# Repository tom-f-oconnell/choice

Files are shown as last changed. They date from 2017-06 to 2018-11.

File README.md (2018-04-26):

### Installation
1. [Install ROS Kinetic](http://wiki.ros.org/kinetic/Installation) on a supported operating system.  
   - Tested on [Ubuntu 16.04](https://www.ubuntu.com/download/desktop).
   - You can install Ubuntu alongside Windows with minimal effort.
   - Other ROS versions may work, but tested with Kinetic.
   - You only need `ros-kinetic-ros-base`.
      - You do *NOT* need everything in `ros-kinetic-desktop-full`, and it takes more disk space and install time.

2. Install the catkin packages.
   See ROS [tutorial on making a catkin workspace](http://wiki.ros.org/catkin/Tutorials/create_a_workspace).

   If you have not already, add a line to your `~/.bashrc` that loads the development setup script (that catkin generates), such as:
   ```
   source <your_catkin_workspace>/devel/setup.bash
   ```

   Then this should install all the packages you need:
   ```
   cd <your_catkin_workspace>/src
   git clone https://github.com/tom-f-oconnell/multi_tracker.git
   git clone https://github.com/tom-f-oconnell/usb_cam.git
   git clone https://github.com/tom-f-oconnell/rosserial.git
   git clone https://github.com/tom-f-oconnell/metatools.git
   git clone https://github.com/tom-f-oconnell/stimuli.git
   git clone https://github.com/tom-f-oconnell/choice.git
   cd <your_catkin_workspace>
   catkin_make
   . ~/.bashrc
   ```

   The last line loads `<your_catkin_workspace>/devel/setup.bash` because of the line you added to your `~/.bashrc` in the previous step.

   On all of the computers in the Hong lab, the catkin workspace can be found at `~/catkin`, for whichever user account was used to run the experiments.

   Currently, only installation from source is supported. In the future, I would like to make this installable as a ROS package via apt, but that would likely also require the same of `multi_tracker`, and there are some technical reasons that won't be possible right now with ROS Kinetic.

3. Upload the firmware to an Arduino MEGA
   1. Download and unzip Arduino to a path you will remember, or locate it if already installed.
      - Version ~1.5 - 1.8.3 should definitely work. Nearby versions almost certainly also will. You should get error messages when compiling if things do not work, and if this is the case you may need to use a different version of Arduino.
      - Arduino older than or equal to 1.0 will likely not work.
      - I unzipped Arduino to my home directory, which came out as as `~/arduino-1.8.3`, which I will use as an example.
   2. `cd ~/arduino-1.8.3/libraries` (or wherever your Arduino is installed)
   3. `rm -rf ros_lib` (in case some libraries have already been generated)
   4. `rosrun rosserial_arduino make_libraries.py .`
   5. Symlink to `stimuli` and `multishock` libraries. You only need
      `multishock` if uploading code that relies on the shift-register based
      shock control hardware.

      (still from `~/arduino-1.8.3/libraries`)
      ```
      ln -s ~/catkin/src/stimuli/arduino/libraries/stimuli
      ln -s ~/catkin/src/choice/arduino/libraries/multishock
      ```

   6. If you Arduino IDE was open, close and re-open it.
      - *Make sure that you are opening the same version of Arduino you installed the libraries for.* It is easier to only have one version of Arduino installed at any given time to avoid these conflicts.

   7. Add your user to the `dialout` group (if on Ubuntu), to be able to upload code.
      - `sudo adduser <username> dialout`
      - Log out and back in for the change to take effect

   8. Connect your Arduino MEGA to the computer.
      - Arduino's with less memory will currently **NOT** work, as there is considerable overhead in the generated ROS libraries.

   9. Upload code 
       
      For the basic stimulus delivery, open `File->Examples->stimuli->stimuli` 
      In the Arduino IDE, under the `Tools` menu:
      - Select appropriate port
         - Usually `/dev/ttyUSBX`, where `X` could vary. `/dev/ttyACMX` may also work. It is never the one like `/dev/ttyS0`.
         - May have the correct board model in parentheses after the port name
      - Select appropriate board (probably `Arduino/Genuino Mega or Mega 2560`)
      - Press the Upload button in the top left of the IDE
         - It looks like a circle with a righward arrow in it.
      - If the TX / RX lights flash on the Arduino, and the Upload seems to finish, you should be good to go.

4. *(Optional)* Set an alias for running `roslaunch` with a different `ROS_HOME` environment variable.

To load the configuration files from (and to save the output directory to) the current directory, I prefix the `roslaunch choice choice.launch` command with `ROS_HOME=``pwd```. To make all `roslaunch` invokations behave this way, which works for my purposes, you can make an alias for `roslaunch`.

If you don't already have a ~/.bash_aliases file, you can create one by opening it in a text editor, otherwise just open the file you already have. Add a line that says:
```
alias roslaunch='ROS_HOME=`pwd` roslaunch'
```

Save and close the file, and reload your terminal environment by typing `. ~/.bashrc`, or opening a new terminal. Now you can just type `roslaunch choice choice.launch`, and it will load configuration input from the current directory and save output there as well.

### Manufacture

TODO link to a readme in the design folder / wiki?

### Running an experiment

#### Requirements
The current directory has at least the following configuration files:
##### For tracking
- tracker_parameters.yaml
- roi_finder.yaml
- delta_video_parameters.yaml

- If running the tracking in real-time, also:
   - liveviewer_parameters.yaml
   - data_association_parameters.yaml
   - kalman_parameters.py

##### For stimulus
- stimulus_parameters.yaml

Depending on the camera you are using, you may also want to include parameters for your camera node, which you will have to load separately. There are some examples in the `multi_tracker` repository.

To copy templates for each of these configuration files to your current directory:
```
rosrun choice copy_configs.py
```

##### To set the length of the experiment
In the `stimulus_parameters.yaml` file, set the parameters starting at `olf/training_blocks` and ending at `olf/beyond_posttest_s` to appropriate values.

In `tracker_parameters.yaml`, set `multi_tracker/record_length_hours` to -1, so
that the length of the recording is determined by the stimulus presentation.

#### To run a full experiment with real-time tracking on the same computer.
Requires a computer with adequate memory and processor.
```
roslaunch choice choice.launch
```

##### Errors (red text)
The only error message that is normal during startup is one along the lines of `Parameter stimulus_arduino/debug does not exist`. Another other red text means something is likely not working, and you should not ignore it.

##### Warnings (yellow text)
`Failed to get param: timeout expired` is normal, as long as the program ultimately stops 
emitting these warnings. You should be aware of the reasons other warnings occur. 
Contact Tom with any questions.

#### To run an experiment saving a background subtracted video in a ROS bag file, for offline tracking.
Less hardware demands.
```
roslaunch choice choice.launch video_only:=True
```

##### Possible problems

If you run `rosparam list` before starting an experiment, you should see
`ERROR: Unable to communicate with master!`, otherwise, the existing parameters
can misconfigure any experiments you try to run.

First, check it isn't a valid experiment being run on another account, if you're
sharing the computer. If not, you should be able to stop the existing `roscore`
process with:
```
sudo pkill rosmaster
```

After this command, you another `rosparam list` should give you
```
ERROR: Unable to communicate with master!
```

### Stimulus Validation

To run the stimulus presentation that would happen during an experiment, but without any 
recording or tracking. For measurement / verification / PID purposes.
```
roslaunch choice choice.launch stimuli_only:=True
```

To run simpler pulse trains of a given duration, without changing the code on the Arduino. 
This launch file will also look for a `stimulus_parameters.yaml` file in the same path, but
with slightly different parameters.
```
roslaunch stimuli pid.launch seconds:=30
```

See [this repo](https://github.com/tom-f-oconnell/stimuli#validation) for more information 
on the parameters and launch file arguments for `pid.launch`.

To test the valves (I run this before and after each experiment, to make sure no connections came loose. With more robust electronics this might be less of a concern.)
- The number of the pin to be switched will be printed in the terminal you run the launch file from.
- I attach higher pressure air to all valves and check manually for air flow at each pin that should be switched.
```
roslaunch stimuli test_valves.launch
```

Press `<Ctrl>-C` to stop the `test_valves.launch` file.

### Offline tracking

#### Requirements
- The environment variable `DATA_DIR` is set to a path you will keep your data directories beneath.
   - I organize my experiment directories as grandchildren of `DATA_DIR`, grouping them as I see fit with directories (of arbitrary names) just beneath `DATA_DIR`.
   - To test that this is set, you can run `echo $DATA_DIR`, and the path should be printed.
   - To set this:

     Add a line to your `~/.bashrc` file like:

     ```
     export DATA_DIR="<full_path_to_data_directory>"
     ```

     For instance, mine has this line:
     ```
     export DATA_DIR="$HOME/data"
     ```

     Then, either start a new terminal, or run `. ~/.bashrc`, so that the change in the environment variable takes effect.

- `$DATA_DIR/retracked` exists and has all of the configuration files required for tracking (see requirements for running an experiment above)
- All of the installation instructions for at least ROS and the `multi_tracker` package are done.

On any computer satisfying these requirements, run:
```
rosrun multi_tracker retrack_ros <experiment_directory> <decimal_valued_rate>
```

The `<decimal_valued_rate>` can be set as high as does not produce a stream of warning messages that does not improve until the tracking finishes.  If the computer appears to be straining, you may also want to decrease the rate.  If you want to also employ more limited computers for tracking lots of data, you are also able to decrease the rate beneath 1.0 if necessary.

The default rate is currently 0.8, if no rate is provided. Our analysis workstations can track up to a rate of 4.0 - 5.0, with little issue.

The `<experiment_directory>` can be any of:
- ~~a path to a valid directory~~
- ~~a file within a valid directory~~
- the name of a subdirectory beneath `$DATA_DIR`, if the `DATA_DIR` environment variable is set
   - the way this script currently finds the output path, it requires `DATA_DIR`, so you should use this option for now.

A valid directory has:
- at a minimum:
   - a name in the `YYYYMMDD_HHMMSS` format
   - a bag file
   - any background PNGs that were in the same directory
   - a file with the ROIs called `compressor_rois_<experiment_id>.yaml`
- ideally, all files generated during acquisition, including also:
   - a `*_parameters.yaml` file
   - a `*_stimuli.p` file

#### Example
```
rosrun multi_tracker retrack_ros 20170930_164433 2.0
```

In this example, `DATA_DIR` was set with a line in my `~/.bashrc` file as:
```
export DATA_DIR="$HOME/data"
```
and `/home/tom/data/20170920/20170930_164433` was a valid directory. Note that `20170930_164433` was not a direct child directory of `DATA_DIR`. The code may currently expect the `<experiment_directory>` to be a granchild of `DATA_DIR`, if this option is selected.

#### Output
After running the tracking, the valid directory you provided as input will also have:
- An HDF5 file with a the variables the tracker is estimating, over time
   - The `position_x` and `position_y`

#### Copying data from acquisition to tracking / analysis computer

You are of course free to copy the files via other means. This may just end up being convenient.

#### Requirements
- Both computers have internet access
- The computer you are trying to connect TO has an SSH server installed and running
   - Look up how to install OpenSSH server for the operating system you are using if you need to do this.

```
rsync -auvPzr <folder_with_data> user@<server_ip_address>:~/<place_to_put_it>
```

The rsync command with those flags seems not to work if you include a trailing slash after the `<folder_with_data>` name.

#### Example
```
rsync -auvPzr ~/data/. tom@gerty:~/data
```
This example will recursively copy all subdirectories of data, and I keep all my experiment directories nested within here.

#### Known bugs + workarounds
If you notice your computer working harder than it should when the acquisition / tracking should otherwise have terminated, you can run `top` or some other process manager, and check for a handful of processes, owned by the same user that ran the launch file, with names including:
- `play`
- `record`
- `python`
- `<something>launch` ?

And assuming you are OK killing all ROS processes currently running on your computer, you can try running:
- `killall roscore`
- `killall roslaunch`
- `killall play`

Under some circumstances, you may also want to kill all python processes owned by the user that started the ROS processes, with `killall python`.

### Analysis
#### Requirements
(To be added )
- `DATA_DIR` is set as in offline tracking instructions.
- `choice` and `multi_tracker` are installed as above (though you don't technically need all of ROS)
- The experiments you want to analyze together have their data folders grouped within an immediate subdirectory of `$DATA_DIR/retracked`.
   - If your tracking output comes from real-time tracking, it does not need to be treated differently, apart from copying it to a subdirectory beneath `$DATA_DIR/retracked`.
- The `ruamel.yaml` package, which you should be able to get via:
   ```
   cd <choice>
   pip install -r requirements.txt
   ```
   Again, if you need root access to install via `pip`, use `sudo` as above.

#### Running
```
rosrun choice choice_analysis <subdirectory>
```

If, across all analysis runs *that have used this folder as input*, you have not already labelled all experiments as either good or needing rejection for some reason, a GUI should open asking you to label the traces appropriately. See the terminal output for which keys correspond to which labels.

The output of this labelling should be saved as `$DATA_DIR/retracked/<subdirectory>/analysis_rejects.yaml`. It is human readable, and you can edit it by hand in a text editor if you want to change something. If you want to start the labelling over, feel free to delete or move / rename `analysis_rejects.yaml`.

Currently, if you want labels to apply across groupings of your data, (across analysis runs with different subdirectories as input) you will need to manually merge the `analysis_rejects.yaml` text files.

#### Output

Within the `$DATA_DIR/retracked/<subdirectory>`, you should find a number of files in a graphics format (svg by default). For each odor, each reject category, and each preference metric (fraction of time spent and "decision bias"), you will find:
- `<metric>.svg`
   - For pooled data of all non-rejects, across all odors.
- `<odor>_<metric>.svg` (or .other_graphic_format, like .png)
   - For pooled data of all non-rejects, within an odor.
- `<reject_category>_<metric>.svg`
   - For data of all rejects of a certain label / category, pooled across odors

There will also be text output, in the terminal in which you ran the analysis, describing the metrics within and across odors, and the fraction of flies in each reject category.

### Updating code

If you have made any changes to your local copies of these repositories that you would like to keep, look up `git stash` and proceed with caution, otherwise:

```
roscd multi_tracker
git pull
roscd choice
git pull
```

Then, repeat the instructions for installing catkin packages above, which should look like:
```
cd <catkin_workspace>
catkin_make
. ~/.bashrc
```

This, again, requires that you have a line in your `~/.bashrc` that "sources" (loads) the file `<catkin_ws>/devel/setup.bash`, or else the line `. ~/.bashrc` will not necessarily apply all updates that have been made to the code.

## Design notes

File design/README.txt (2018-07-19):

If any .svg or .fcstd files are newer than files of the same name with a
different extension (should be .eps and .stl, respectively), then you may want
to delete those .eps and .stl files and re-generate them from the newer source
files before cutting / printing the parts.

SVGs are Inkscape SVGs. Generally I would export these as EPS and then load them
on the computer connected to the laser cutter in Coreldraw.  In Coreldraw, I
would convert all lines to "Hairline" , as this was required for any lines you'd
like to cut (<0.0001" should be treated the same, but it is harder to work with
while designing).

.fcstd files should be openable with FreeCAD. The software is getting a lot
better, so it is worth getting the most recent version from the PPA (you can
look up how to do this). I generally used version 0.17. To export STLs you have
to open the FCSTD file, select an object (on the left, the highest level node
that isn't the name of the document), and then go to File->Export and change the
output file type to STL.  I prepared gcode (instruction for the 3D printer) in
Cura, on Windows, because this is what our librarian showed me how to use.

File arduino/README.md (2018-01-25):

## multishock Arduino library

Wiring/Arduino library to control shock delivery and measurement board. 
Can deliver up to 150v to 16 channels, and measure current through each of them.

### Installation

Copy the `libraries/multishock` directory to one of the library folders for 
your current Arduino installation. This may be `~/Documents/Arduino/libraries/`,
but search online for other situations. This is generally how Arduino 
libraries are installed.

To keep the code update to date more easily, you may want to make a symbolic
link to this directory, rather than copying it. To do this:
```
ln -s /full/path/to/libraries/multishock/ /path/to/arduino/libraries/
```

### Usage

See example sketches. After installing, open / re-open your IDE, and open one 
of the examples under `File->Examples->multishock`

### Testing assembly of the board

See sketches under `examples->tests` folder. Each should explain, at the top of
the file, how to determine whether the test was successful.

TODO

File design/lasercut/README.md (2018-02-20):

- `olfactory_shock_conditioning_chambers.dxf`
   - Master design file for lasercut layers of two choice behavior chambers.
   - Layers in the same plane have the same prefix number (before the period).
   - Lower prefix numbers are layers higher in the assembly.
   - TODO include materials and sources for all layers

- `floor_pcb_edges.dxf` and `ceiling_pcb_edges.dxf`
   - Generated from one version of `olfactory_shock_conditioning_chambers.dxf`
   - Imported into Kicad to the `Edge.Cuts` layer to form the outline and 
     interior routed / drilled features of the floor and ceiling circuit boards.

- `food_vial_holder_no_slider.svg`
   - A prototype food vial holder, to serve as a source of flies for an automatic
     loader.
   - TODO list related parts in 3D printed folder.
   - This master was created in Inkspace. May not load correctly in other programs,
     as it is a special Inkscape SVG format.

- `shaft_output_doubler.dxf`
   - Mounting plates to mate two of the following 70mm gears .
   - Meant to keep the heads of two fly sorters aligned, so when one is at a 
     valid outlet, so is the other.
   - TODO mention related 3D models
- `generated_70mm_gear.svg`
   - TODO how was this generated again? online utility? inkscape script?
   - TODO has this since been copied to `shaft_output_doubler.dxf`? delete?

- `vacuum_trap_for_engraving_0.3.dxf`
   - Prototype of a modular vacuum trap that would be used in isolation.
   - Based quite directly on designs from Ben de Bivort's lab.
   - TODO include laser cutter instructions / power file
- `modular_vacuum_trap.dxf`
   - Unclear whether this was the master or the above was. Neither is rendering 
     properly for me now.

- `smaller_boardcam_mount.dxf`
   - Acrylic adaptor to attach top-down camera to 1" aluminum rail
   - TODO include link to camera / model of one

Other files ending in `.svg` or `.eps` are (potentially outdated) exports 
generated from the `.dxf` of the same name. These are for laser cutting, or use
in other programs. They were generated in Librecad, the same program used to 
draw the master DXFs. These intermediates should load OK in at least Coreldraw.

To get a DXF suitable for import into KiCAD, for use as the outline of the
board:
- Make a copy of the DXF with the edges you want
- In the copy (at least relevant to LibreCAD):
  - delete all layers / features other than the edges
  - select any blocks in your design and `Tools->Modify->Explode` them
  - delete all blocks
- (temporarily) change page settings in KiCAD PCB Layout Editor view of either
  the ceiling or the floor board, whichever you want to import new edges to.
  - `File->Page Settings->Orientation->Landscape`
- `File->Import->DXF`
- Change page settings back to portrait, so boards fit on page for printing.

TODO put this in a README in PCB directories somewhere
To generate negative of copper layer for etchant mask:
- (in KiCAD) `File->Plot`
- Select `SVG` from dropdown
- Check `Mirrored plot` and `Negative plot`
- Change any other settings you want, including perhaps what to do with edges.
- Plot
- Print the SVG output in some program that maintains scale (Inkscape works)

The existing negative is in `design/pcb/gerber/ceiling/<...>.svg`.

#### TODO
- maybe delete all of either the SVGs or the EPS
- maybe generate all of one or both for all files
- maybe store generated files separate from the masters (whether Inkscape SVG or DXF)

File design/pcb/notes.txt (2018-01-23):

power usage (measured):
-v0.1 (manually fixed pinswaps on both power supply ICs)
-all digital chips in, no analog
-all other caps and resistors attached
-2 channels worth of FET / measurement resistors + diodes fully attached
-150R gate resistor on all other channels
-LEDs + 100R with + side on gate and - side on S, in each mosfet socket
-Uno 5V -> 10A fused connection on radioshack true rms meter, negative meter -> shield 5v Uno gnd <-> shield gnd
-Uno powered with 12v, 1A wall-wart. no USB cable connected.
-optoisolator inputs floating

~0.54 A on radioshack meter (on range w/ 1 digit to left of decimal point. in Amps.)
voltage at Vin +/- on DCP020507P (measured with a second meter): ~4.4-(4.6?)v

same, but w/ Mega R3 from Elegoo
v=(~4.4-4.3)->4.2->4.17->still dropping by hundreths of volts after test discontinued 
after a few seconds
I=0.5->0.32

(these two tests actually had the LED + resistors going from gate to drain,
 and so doing nothing, because there was no h.v. power supply attached.
 this was because pinswap of D and S by mistake in v0.1)

TODO why such poor regulation? 12v leaves plenty of headroom, shouldn't it?

TODO do some tests w/ better 5v bench supply, see what current draw would be

-> getting close to needing a separate supply, maybe doing away with the dcp020507
   and just having the lt1118 downstream of a wall wart or something (would need
   this power supply to provide isolation though...)

now with Uno and LED + resistors actually connected from gate to source
V=4.7->4.6ish
I=.625->.6
over maybe 10 seconds

in each of these tests, the Arduino's regulators have gotten fairly hot.
-maybe use diff input voltage?

optoisolator test (on PCB):
-using Uno w/ same wall-wart as above
-test code w/ TEST_ISOLATORS, 3000ms period, all isolator pins on/off
-all digital ICs other than optoisolators (also) disconnected

voltage on output pins of isolators (~0.23, 5) (low, high)
only arduino regulator seems to be getting hot, but not as much as it has
(felt through Arduino PCB)

(limited) test of overvoltage protection
-testing one channel on one of the v0.1 pcbs.
-one channel D->S shunted, no MOSFETs in
-two channels on this PCB fully constructed (diodes, etc) (0 and 15)
    -only these two channels had D,S swap fixed
-other channels just have gate resistor
-all other circuitry assembled (two amplifiers not in sockets though)

3mA @ 120v. for some reason, zener on this channel never seemed to exceed ~2.2V
(test w/ isolated 39K resistor in series w/ same zener produced either 0.8V one
way, or expected 4.8-5.1V the other way)

-using sper scientific 800005 w/ what seems like a K type probe
    -only really able to get a small fraction of the probe's surface on the
     tested part, rest is just exposed to air
    -after ~1-3min @ 120v (was probably still ~3.1mA whole time)
     39K 1W resistor: ~46C (might have seen 48C once)
     zener diode (maybe larger b/c proximity to 39K?: 36(-38?)C
     measurement resistor also in low to mid 30s (presumably entirely b/c
     proximity to 39K)

    -probe is at least also reading ~24.3 @ RT (not sure about calibration
     though). no real reason to think it is off, but haven't tested.

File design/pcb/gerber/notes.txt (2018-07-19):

exported following instructions here:
https://citizengadget.com/post/139813545072/kicad-to-advanced-circuits-for-pcbs-and-assembly

copying important section here:
To generate the gerbers in pcbnew, click plot icon or File->Plot. This Wayne and
Layne post on Gerber generation was super helpful here.

    Layers, probably F.Cu (Top Copper), B.Cu(Bottom Copper) F.Paste(Top Solder
    Paste) F.Silk (Top Silkscreen), B.Silk (Bottom Silkscreen), B.Mask (Bottom
    soldermask), F.Mask (Top soldermask)

    Options, You might have other stuff checked, but the important one is to
    make sure Exclude PCB edge layer from other layers is unchecked as Advanced
    doesn’t take a separate edge cuts layer. Another nicety is check use
    auxiliary axis as origin so when you view in gerbview the file is in the
    center of the screen.

    Gerber Options, click Protel filename Options.

    Finally, Click Plot.

Now to generate the drill file, click Generate Drill File.

    Drill Units, use inches
    Zeros format suppress leading zeros
    Drill Map doesn’t matter
    Files options uncheck mirror y, use minimal header, and if you have non
    plated holes, Advanced takes a separate file for plated and non plated so
    make sure merge pth and npth holes into one file is unchecked.

    Drill Origin Auxiliary axis presuming you used “auxiliary axis as origin” in
    the plot screen. 

    Finally, click Drill File then Close and Close and you Gerbers are in your
    project directory under GerberOutput

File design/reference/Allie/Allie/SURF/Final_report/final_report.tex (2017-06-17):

%%%%%%%%%%%%%%%%%%%%%%%%%%%%%%%%%%%%%%%%%
% University/School Laboratory Report
% LaTeX Template
% Version 3.1 (25/3/14)
%
% This template has been downloaded from:
% http://www.LaTeXTemplates.com
%
% Original author:
% Linux and Unix Users Group at Virginia Tech Wiki 
% (https://vtluug.org/wiki/Example_LaTeX_chem_lab_report)
%
% License:
% CC BY-NC-SA 3.0 (http://creativecommons.org/licenses/by-nc-sa/3.0/)
%
%%%%%%%%%%%%%%%%%%%%%%%%%%%%%%%%%%%%%%%%%

%----------------------------------------------------------------------------------------
%	PACKAGES AND DOCUMENT CONFIGURATIONS
%----------------------------------------------------------------------------------------

\documentclass{article}

\usepackage[version=3]{mhchem} % Package for chemical equation typesetting
\usepackage{siunitx} % Provides the \SI{}{} and \si{} command for typesetting SI units
\usepackage{graphicx} % Required for the inclusion of images
\usepackage{natbib} % Required to change bibliography style to APA
\usepackage{amsmath} % Required for some math elements 

\setlength\parindent{0pt} % Removes all indentation from paragraphs

%\renewcommand{\labelenumi}{\alph{enumi}.} % Make numbering in the enumerate environment by letter rather than number (e.g. section 6)

%\usepackage{times} % Uncomment to use the Times New Roman font

%----------------------------------------------------------------------------------------
%	DOCUMENT INFORMATION
%----------------------------------------------------------------------------------------

\title{Quantitative measurements of olfactory perceptual thresholds in \textit{Drosophila}} % Title

\author{Allie Hexley} % Author name

\date{\today} % Date for the report

\begin{document}

\maketitle % Insert the title, author and date

\begin{center}
\begin{tabular}{l r}
SURF Summer 2016 \\ 
Mentor: Elizabeth Hong 
\end{tabular}
\end{center}

% If you wish to include an abstract, uncomment the lines below
\begin{abstract}
Previous work has identified the molecular, genetic, and circuit substrates for odor-driven behaviors in \textit{Drosophila melanogaster}, but has yet to quantify the performance limits of such odor-driven behaviors. The goal of this project was to make quantitative measurements of the threshold for odor detections and discrimination in \textit{Drosophila} to help better the understanding of the neural codes underlying behavior. In order to make these measurements a purpose built behavioral chamber was built where the \textit{Drosophila} were trained via classical conditioning (via electric shock). The \textit{Drosophila} were presented with two odors and innate preferences noted, and then trained against one of the odors. Following conditioning the \textit{Drosophila} were presented with the aversive odor and neutral odor and post-conditioning preferences were recorded. When training against both 5\% MCH compared to OCT and 3\% MCH compared to OCT, \textit{Drosophila} were able to learn an aversion towards the MCH, but when training against 5\% MCH compared to 3\% MCH or vice versa, the \textit{Drosophila} were unable to learn any aversion. This could be because the \textit{Drosophila} are unable to discriminate between 5\% MCH and 3\% MCH or because the \textit{Drosophila} are generalizing the learned aversion. Future studies must be done with a larger number of concentrations across a greater interval to see how learned aversion varies along the concentration curve, and neuron spike rate should be recorded along the concentration curve also, to show how the change in behavior and change in neural activity relate to each other in order to better quantify perceptual thresholds.
\end{abstract}

%----------------------------------------------------------------------------------------
%	Introduction
%----------------------------------------------------------------------------------------

\section{Introduction}

Previous work has revealed the molecular, genetic, and circuit substrates for odor-driven behaviors in \textit{Drosophila melanogaster} (Wilson, 2013). However there are few measurements of the perfomance limits of such odor-driven behaviors in flies, and these measurements are a necessary step towards understanding the neural codes underlying these behaviors. Whilst the ability of \textit{Drosophila} to discriminate between two different odors, and to have an innate bias towards specific odors has been demonstrated (Parnas \textit{et al.}, 2013), the thresholds for odor detection and discrimination have not yet been identified. My SURF project focused on building custom-built apparatus to probe these thresholds and running experiments to collect preliminary data to begin to make quantitative measurements of the performance limits of odor-driven behaviors. Ultimately the goal of the project is to produce curves showing how \textit{Drosophila} behavior varies with concentration of odor presented and how neuron spike rates change with concentration of odor presented, and to compare the two in order to examine how change in behavior relates to change in neural activity at different concentration changes.\\

\textit{Drosophila melanogaster} were used as the subject of the experiments I ran because they have a numerically compact brain, and a sophisticated genetic toolbox for manipulating circuit functions. Most olfactory neurons are also steretoyped in \textit{Drosophila}, meaning one can find neurons with the same connectivity and physiology in every individual brain. \textit{Drosophila} also have genetic labels for specific neurons and these labels can be used to target specific neurons for electrophysiological measurements. In \textit{Drosophila} odor is detected by the primary olfactory center, the antennal lobe (Tanaka \textit{et al.}, 2012), which has a glomerular structure. Each glomerulus receives input from a certain type of olfactory receptor neuron, creating a map of the odor quality. Output projection neurons innervate the antennal lobe to take information to higher brain regions. This organization of the antennal lobe allows for parallel procession of olfactory input by many parallel coding channels, each of which can be genetically identified.\textit{Drosophila} can be easily trained via Pavlovian conditioning to acquire aversion to a particular odor. It is important that we train the flies used in our studies to ensure that we are driving them to their performance limits in terms of discriminating odor, to ensure that we can quantify the minimum odor concentration difference that the flies are able to distinguish.\\

Pavlovian olfactory conditioning has been used in previous studies (Claride-Chang \textit{et al.}, 2009) to train flies against 4-methycyclohexanol (MCH) and 3-octanol. Claridge-Chang et \textit{al.} used 5\% MCH and 12\% OCT in aversive training against MCH, and found that in mock conditioning (where presentation of MCH was not paired with an electric shock during training), innate preferences were maintained, and in conditioning trials (where presentation of MCH was paired with an electric shock), flies learned aversion against MCH (Figure 1). Claridge-Chang et \textit{al.} also used a behavior chamber design that allowed for individual tracking of fly movements and demonstrated that individual fly preferences changed to become more aversive to MCH during conditioning trials and that individual preferences were not changed during mock conditioning (Figure 2). My SURF project aimed to create a behavior chamber similar to the one used by Claridge-Chang et \textit{al.} to probe perceptual thresholds, and a good test of the effectiveness of this chamber would be to reproduce the Claridge-Chang et \textit{al.} results. \\

%Claridge-Chang group data 1
\begin{figure}[h]
\begin{center}
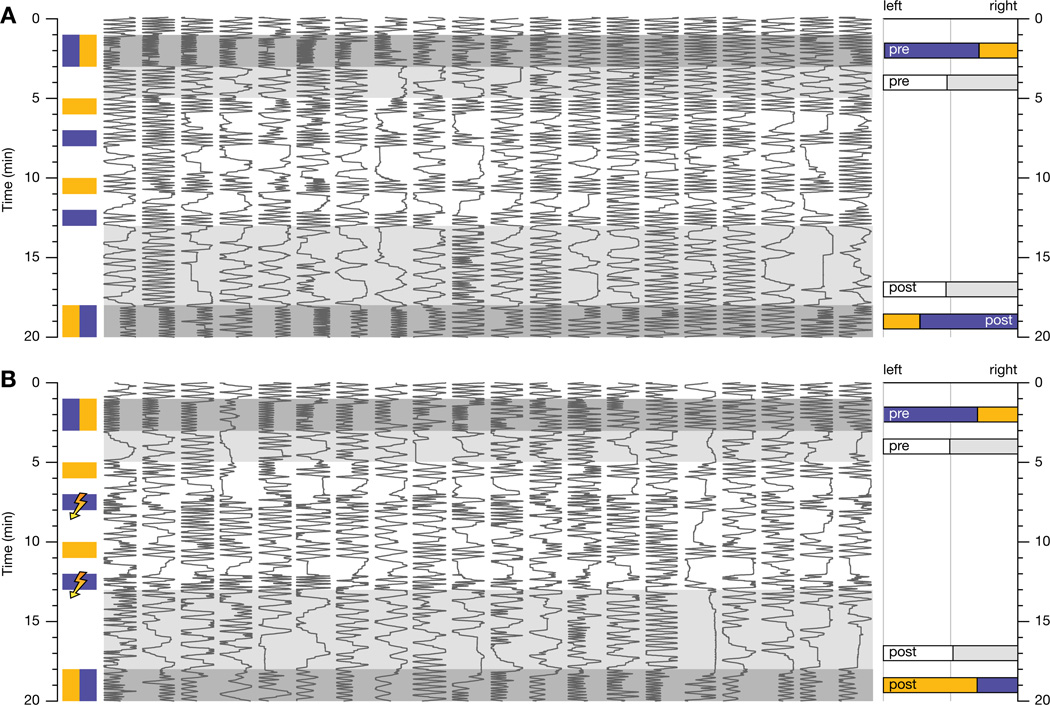
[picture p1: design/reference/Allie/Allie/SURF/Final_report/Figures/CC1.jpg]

\caption{Results from Claridge-Chang et al., 2009, showing the flies positions in a behavioral chamber over time, chosing between MCH (blue) and OCT (yellow). A) Mock conditioning shows innate preferences are preserved. B) Pairing the presentation of MCH with electric shock causes learned aversion of MCH.}
\end{center}
\end{figure}

%Claridge-Chang individual data 2
\begin{figure}[h]
\begin{center}
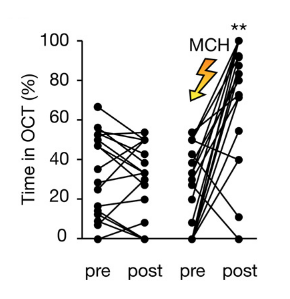
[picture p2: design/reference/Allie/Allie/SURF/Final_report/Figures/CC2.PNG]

\caption{Individual fly data showing time spent in OCT before and after mock conditioning (individual innate preference is maintained) and before and after pairing MCH with electric shock (flies show increased aversion to MCH).}
\end{center}
\end{figure}

%----------------------------------------------------------------------------------------
%	Methods
%----------------------------------------------------------------------------------------

\section{Methods}

My SURF project aimed to quanitfy perceptual thresholds in \textit{Drosophila} by seeing how behavior varies with concentration of odor presented. To run the experiments necessary to do this I had to build a custom-built behavior chamber that allowed for individual fly movement tracking, two odors to be presented simultaneously to each fly, presentation of an electric shock to each fly paired with presentation of an odor, and ideally for all of the above to be controlled automatically. I designed and built such a chamber, and spent most of the ten weeks of my SURF project doing so (Figure 3). The chamber was designed to house eight flies at a time, and a PCB electrode acted as the floor of the chamber such which could be charged such that the flies would receive an electric shock when stepping on the floor board (which they were doing at all times when in the chamber) (Figure 4). An odor flow system was designed to pump odor into each of the corridors where the flies were housed (Figure 5). Mass flow controllers and valves controlled the odor flow into the corridors. The corridors were imaged by a PointGrey CCD camera, and MATLAB Image Acquisition ToolBox was used to record videos of the fly movements inside the chamber (Figure 6). Fly movements could be tracked either by using Ctrax software or by manually scoring the videos for either the number of times a fly entered one half of the chamber from the central choice zone, or on the position of the fly in the chamber and randomized frames of the video.\\

%chamber_images 3
\begin{figure}[h]
\begin{center}
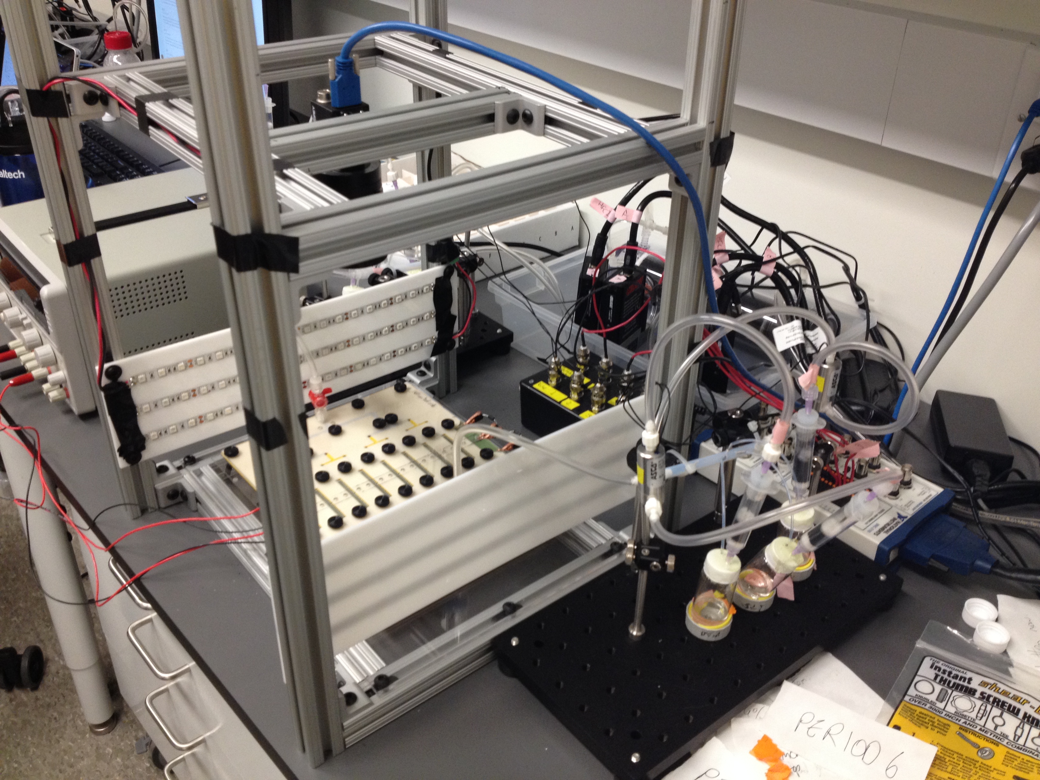
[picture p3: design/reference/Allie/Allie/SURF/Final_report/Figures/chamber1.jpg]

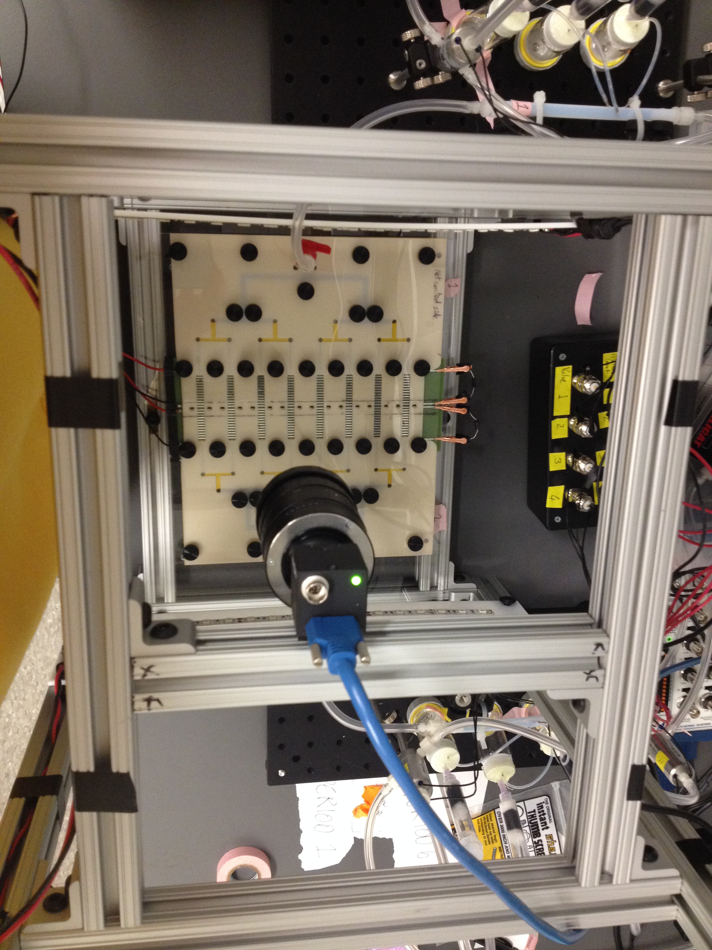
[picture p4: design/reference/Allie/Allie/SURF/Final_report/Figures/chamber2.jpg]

\caption{Photographs of the fully constructed chamber. Note when experiments are running the chamber is covered in a black draping to keep light out and the chamber is illuminated via infrared LEDs from the sides.}
\end{center}
\end{figure}

%chamber_schematic 4
\begin{figure}[h]
\begin{center}
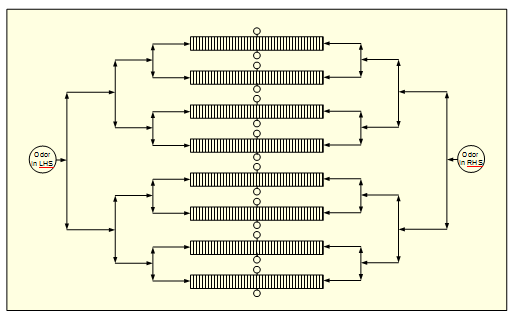
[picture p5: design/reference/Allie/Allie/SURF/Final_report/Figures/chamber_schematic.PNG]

\caption{Schematic showing the chamber design. The 8 corridors in the center are where the flies are placed, and the grid indicates the PCB board used to electrify the chamber and shock the flies during conditioning. The arrows represent the odor flow through the chamber.}
\end{center}
\end{figure}

%odor_flow_schematic 5
\begin{figure}[h]
\begin{center}
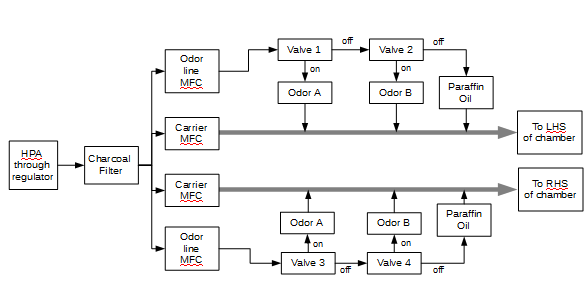
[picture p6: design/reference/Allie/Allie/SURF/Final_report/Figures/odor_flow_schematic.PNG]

\caption{Schematic showing the odor flow from the high pressure air vent into the chamber.}
\end{center}
\end{figure}

%image_acquistion 6
\begin{figure}[h]
\begin{center}
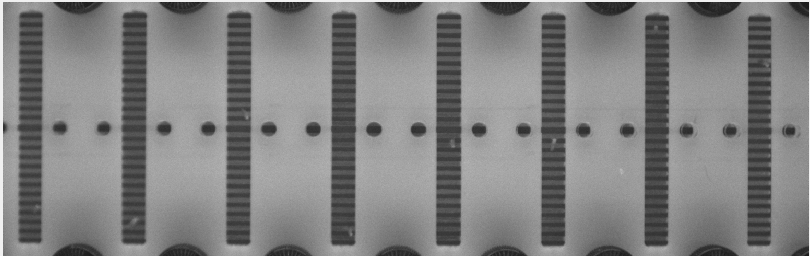
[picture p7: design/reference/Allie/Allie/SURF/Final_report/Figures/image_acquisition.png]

\caption{Screenshot of CCD video acquistion captured using MATLAB image acquisition toolbox showing 8 flies in the chamber.}
\end{center}
\end{figure}

During the last two weeks of the summer I ran some preliminary experiments in the purpose built chamber. I first tried to reproduce the Claridge-Chang et \textit{al.} results by running pre-conditioning trials (presenting 5\% MCH on one half of the chamber and 12\% OCT on the other half of the chamber for 2 minutes to test innate preferences), mock conditioning (presenting 5\% MCH and 12\% OCT across the full chamber for 1 minute intervals twice), conditioning (same as mock conditioning but pairing presentation of MCH with 6 60VDC electric shocks), and post-conditioning trials (presenting 5\% MCH across half of chamber and 12\% OCT across other half for two minutes). All of these trials were run with a population of 8 flies. Then I ran experiments to see how learned aversion generalizes across concentration, by first training with 5\% MCH and testing with 5\%, 4\%, and 3\% MCH, and then by training with 3\% MCH and testing with 3\% MCH, 4\% MCH, and 5\% MCH. I then ran experiments to directly compare 5\% MCH and 3\% MCH, training against either 5\% MCH or 3\% MCH and presenting both odors simultaneously during pre- and post-conditioning to see if the flies could discriminate between the two concentrations. These trials were run with a population of 15 flies. \\

%----------------------------------------------------------------------------------------
%	Results
%----------------------------------------------------------------------------------------

\section{Results}

In the mock-conditioning trials the flies maintained their innate preferences (both as the population mean and individually), and in conditioning trials where the presentation of 5\% MCH was paired with electric shock (as in Claridge-Chang et \textit{al.}) the flies learned aversion to MCH (Figure 7 and Figure 8).\\

%my mock data and group MCH data 7
\begin{figure}[h]
\begin{center}
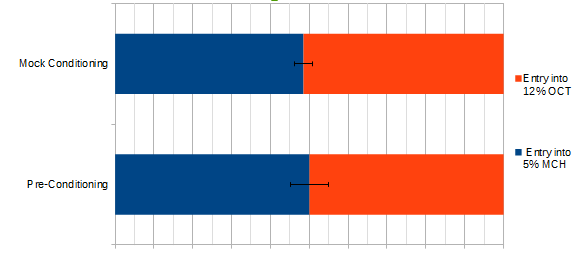
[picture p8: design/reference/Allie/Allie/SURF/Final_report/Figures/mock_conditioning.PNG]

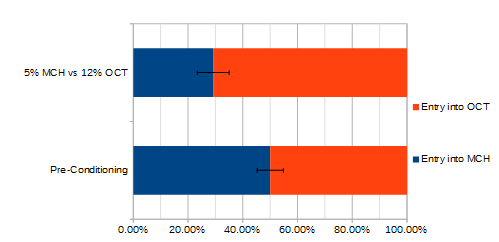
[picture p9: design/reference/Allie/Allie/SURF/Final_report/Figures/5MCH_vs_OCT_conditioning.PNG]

\caption{Top: Mock conditioning. Flies maintain innate preferences during mock conditioning, as expected. Bottom: Training against 5\% MCH. Flies show aversion to MCH after conditioning pairs MCH with electric shock.}
\end{center}
\end{figure}

%my individual data for mock and MCH 8
\begin{figure}[h]
\begin{center}
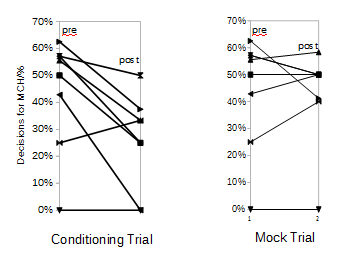
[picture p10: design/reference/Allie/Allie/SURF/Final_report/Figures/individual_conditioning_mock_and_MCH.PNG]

\caption{Left: Individual fly preferences for conditioning trial against 5\% MCH. The majority of individual flies show increased aversion to 5\% MCH after pairing of 5\% MCH with electric shock during conditioning. Right: Individual fly preferences remain consistent after mock conditioning.}
\end{center}
\end{figure}

When the flies were trained against 5\% MCH, and tested with 5\% MCH, 4\% MCH, and 3\% MCH compared with 12\% OCT, the flies learned aversion to 5\% MCH, but this learned aversion did not appear to generalize along the concentration curve and when tested with 4\% MCH and 3\% MCH the flies seemed to revert back to their innate preferences (Figure 9).\\

%my data for 5 percent down conc 9
\begin{figure}[h]
\begin{center}
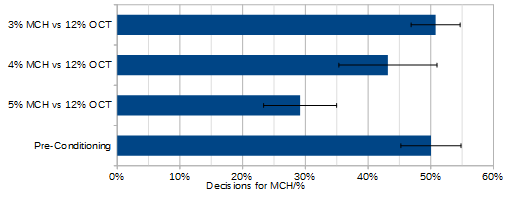
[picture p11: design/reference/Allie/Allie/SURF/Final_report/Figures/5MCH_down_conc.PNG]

\caption{Mean number of decisions into MCH zone for a group of 8 flies at different stages of condtioning by pairing presentationg of 5\% MCH with electric shock. Pre-conditioning shows innate odor preference. Post conditioning testing with 5\% MCH shows increased aversion to 5\% MCH, but testing with 4\% MCH and 3\% MCH shows similar aversion to MCH as pre-conditioned results.}
\end{center}
\end{figure}

When trained against 3\% MCH compared to OCT, and tested with 3\% MCH, 4\% MCH, and 5\% MCH, the flies did not seem to learn any aversion to the 3\% MCH (in terms of the mean decisions for MCH for the population) (Figure 10). However when individual performance was analyzed, the majority of individual flies did learn an aversion to 3\% MCH (Figure 11).

%my data for 3 percent up conc 10
\begin{figure}[h]
\begin{center}
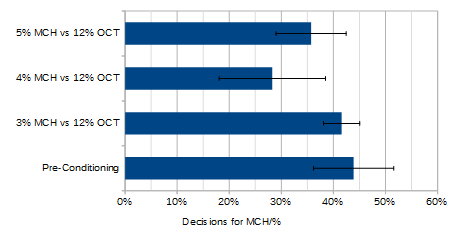
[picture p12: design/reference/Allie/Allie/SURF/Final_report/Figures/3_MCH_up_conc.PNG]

\caption{Mean number of decisions into MCH zone for a group of 8 flies at different stages of condtioning by pairing presentationg of 3\% MCH with electric shock. Pre-conditioning shows innate odor preference. Post conditioning testing with 3\% MCH, 4\% MCH, and 5\% MCH shows similar aversion to MCH as pre-conditioned results, implying no learned aversion when trained with 3\% MCH.}
\end{center}
\end{figure}

%my individual data for 3 percent MCH 11
\begin{figure}[h]
\begin{center}
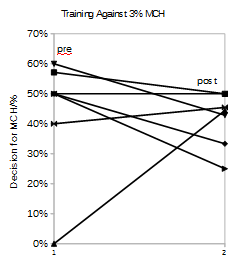
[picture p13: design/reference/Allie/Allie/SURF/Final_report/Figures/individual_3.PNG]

\caption{Individual fly preferences for conditioning trial against 3\% MCH. Most individual flies show increased aversion against 3\% MCH after pairing of 3\% MCH with electric shock during training.}
\end{center}
\end{figure}

Since the flies were able to learn aversion to 5\% MCH compared to OCT and to 3\% MCH compared to OCT, we decided to run an experiment to see if the flies could learn an aversion to 5\% MCH compared to 3\% MCH and vice versa. When trained against 5\% MCH and then presented with 5\% MCH in one half of the chamber and 3\% MCH in the other half of the chamber the flies did not seem to learn an aversion to 5\% MCH (Figure 12). Likewise when trained against 3\% MCH, the flies did not acquire a learned aversion (Figure 13). %my data for 5 percent aversive vs 3 percent MCH 12
\begin{figure}[h]
\begin{center}
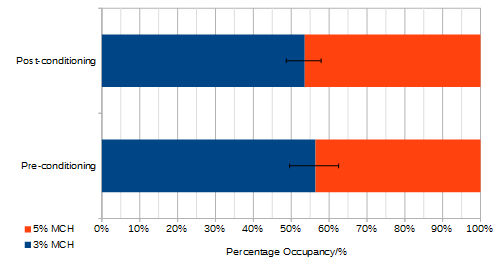
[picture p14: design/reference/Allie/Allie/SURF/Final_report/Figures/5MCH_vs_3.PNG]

\caption{Mean percentage occupancy results for a group of 15 flies before and after conditioning against 5\% MCH. Flies are presented with 5\% MCH on one half of the chamber and 3\% MCH on the other half of the chamber, and preferences between the two concentrations remain constant after pairing the presentation of 5\% MCH with an electric shock.}
\end{center}
\end{figure}

%my data for 3 percent aversive vs 5 percent MCH 13
\begin{figure}[h]
\begin{center}
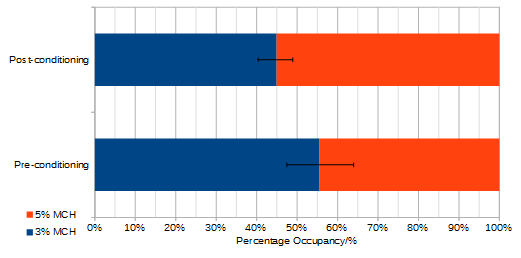
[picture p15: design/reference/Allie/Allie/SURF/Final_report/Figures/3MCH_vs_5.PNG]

\caption{Mean percentage occupancy results for a group of 15 flies before and after conditioning against 3\% MCH. Flies are presented with 3\% MCH on one half of the chamber and 5\% MCH on the other half of the chamber, and preferences between the two concentrations remain constant after pairing the presentation of 3\% MCH with an electric shock.}
\end{center}
\end{figure}

%----------------------------------------------------------------------------------------
%	Discussion
%----------------------------------------------------------------------------------------

\section{Discussion}

Whilst the flies were able to learn aversion to both 5\% MCH and 3\% MCH compared to 12\% OCT, the flies were unable to learn an aversion to either 5\% MCH or 3\% MCH directly compared to the other. This could be because the flies are unable to discriminate between 5\% MCH and 3\% MCH, as these concentrations may be near the saturation point, above which flies cannot tell the difference between two concentrations of odors. To test whether this is the case, future studies could test a wider variety of odors over a much large interval (say 0.01\% MCH compared to 5\% MCH and see if the flies are able to learn an aversion to one of those over the other). Another explanation as to why the flies did not learn an aversion to 5\% MCH or 3\% MCH compared to the other is that they are generalizing the learned aversion i.e. perceiving all concentrations of MCH to be equally as aversive, and if this were the case then one would expect to see that flies would not learn an aversion to say 0.01\% MCH compared to 5\% MCH.\\

The data I presented in this report is all preliminary, and none of the results are statistically significant. Since building the apparatus to run the experiment in took so long, I only had time to run experiments on a very small population of flies and as such the variation of the results is large and no statistically significant conclusions could be drawn. However the results do indicate a trend which should be further investigated by repeating the experiments I have run on a larger population of flies (n=50) and over a larger range of odors (n=10). \\

Once behavioral data has been collected for a larger population of flies over a larger range of odor, neuron spike rates may also be recorded, allowing behavior vs concentration and neural activity vs concentration curves to be drawn and compared to help quantify perceptaul thresholds in \textit{Drosophila.} These experiments could also be ran with a variety of odors to see if concentration curves looked similar for each odor or if it differed depending on the odor used.

%----------------------------------------------------------------------------------------
%	Acknowledgments
%----------------------------------------------------------------------------------------

\section{Acknowledgments}

I'd like to thank my mentor, Elizabeth Hong, for helping me with this project, as well as for providing the funding for my SURF. I would also like to thank every member of the Hong lab who helped me during the summer and for making the work environment safe and fun. I'd also like to thank the SURF program for hosting me and allowing me the opportunity to conduct such exciting research and for making this such a fun summer!

%----------------------------------------------------------------------------------------
%	References
%----------------------------------------------------------------------------------------

\section{References}

\begin{enumerate}

\begin{item}
Wilson RI. Early Olfactory Processing in \textit{Drosophila} Mechanisems and Principles. \textit{Annual Review of Neuroscience.} 2013.
\end{item}
\begin{item}
Moshe Parnas, Andrew C. Lin, Wold Huetteroth \& Gergo Miesenbock. Odor Discrimination in \textit{Drosophila}: From Neural Population Codes to Behavior. \textit{Neuron}. 2013.
\end{item}
\begin{item}
Adam Claridge-Chang, Robert D. Roorda, Eleftheria Vrontour, Lucas Sjulson, Haiyan Li, Jay Hirsh \& Gero Miesenbock. Writing Memories with Light-Addressable Reinforcement Circuitry. \textit{Cell.} 2009.
\end{item}

\end{enumerate}

%----------------------------------------------------------------------------------------
%	BIBLIOGRAPHY
%----------------------------------------------------------------------------------------

\bibliographystyle{apalike}

\bibliography{sample}

%----------------------------------------------------------------------------------------

\end{document}

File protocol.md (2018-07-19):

### Running an experiment

#### Cleaning the chamber

It should take 20-40 minutes to disassemble, clean, and re-assemble the chamber.

1. Disassemble chamber.

    - Take off ceiling and dump / blow flies into a fly morgue.

    - Set aside ceiling, only handling it by the edges. The less stuff that
      comes into contact with the electrodes, the better.

    - Take out all screws.

      - Use 3/32" hex bit in screwdriver to remove button cap screws on the
        sides. The orange toggle switch near the trigger on the screwdriver
        switches the direction.

      - Use 7/64" hex hand driver to remove screws holding the ceiling rails
        down, and the two screws holding the floor circuit board down.

    - Do not take any of the layers apart until the cleaning step.

2. Clean all surfaces that touched the fly with DI water, and all surfaces with
   70% ethanol, diluted with DI water if diluted from a higher concentration.

    - Wear gloves.

    - Do water, then ethanol.

    - Use 1 Kimwipe per solvent per layer to clean. For layers with two parts,
      use one Kimwipe for both parts.

    - Use water on both circuit boards, and the middle third of both the yellow
      and white layers.

    - After cleaning with the water, particularly on the circuit boards, dry
      with another Kimwipe, as pooling of water on the circuit boards could
      damage them.

    - For the circuit boards, wipe with the long axis of the electrodes, to
      minimize risk of delaminating the circuit board.

    - When cleaning the white and yellow layers, try to wipe in the direction of
      the grooves, to minimize how much you shred the Kimwipes. Chunks of
      Kimwipe could interfere with a seal or provide a texture that could
      distract the flies from the task.

    - Clean both sides of each layer, except for the clear acrylic layers. For
      the top acrylic, only clean the bottom, and for the bottom acrylic
      baseplate, you only need to clean the top.

    - Let all parts dry, such that there is no water or ethanol remaining in the
      assembled chamber.

    - Since the Viton (black) layers might not dry well if you let them form a
      seal against the counter top, place each of those parts on a Kimwipe
      to help make sure the bottom can dry as well.

3. Re-assemble chamber

    - Do your best to line the floor circuit board up so that it seems to sit as
      symmetrically as possible with the rest of the geometry of the chamber,
      and that its holes line up well with those of the baseplate.

    - Use two 3/16" long 6-32 screws (the smallest screws of the assembly) to
      secure opposite corners of the floor circuit board. To the sides of either
      spring loaded connector on this circuit board, there should be two holes,
      use one of each of these holes, and not the holes in the parallel lines
      down the side of the board.

    - Line up the thicker two black Viton layers against the sides of the
      circuit board. **There should not be a gap between the circuit board and
      the Viton, as air could escape out the sides if there were.** Place just a
      small amount of the Viton against the acrylic baseplate, and then slide
      the gasket towards the circuit board, paying the most attention to the
      interface between the circuit board and the gasket, but also trying to
      line up the holes in the gasket with the holes in the mounting plate.
      Since the Viton is kind of sticky once much of it is layed flat, if you
      make a mistake, it is often easier to just list the whole thing up to try
      re-aligning it.

        - Holes are symmetric, but there is more material on one side than the
          other. Place in the orientation that centers it best on the baseplate.
          By flipping the gasket over, it could also work just as well on the
          other side.

    - Place down the yellow shimstock layer down. All holes and slots should
      match something on the layers below, and the edges should roughly line up
      with the edges of the Viton. If this layer is not laying flat, lift it up
      and try placing it back down.

    - Place down the white Delrin layer. There are a few holes and slots that
      are in the yellow layer, that are not in the white layer, but all holes
      are that are in the white layer should match holes in the yellow layer.

        - Alignment between the white and layers is not critical at this point.
          You can fix that alignment just before screwing the whole assemble
          together, as the two materials slide against each other easily.

    - Place down the thinner top Viton gaskets, just doing your best to align
      the holes with the white layer beneath.

        - Same note on symmetry / orientation as with the thicker Viton gaskets.

    - Now place the top acrylic sides on.
    
        - Since both the acrylic and the white layers stick the the Viton, you
          will need to get the acrylic in the orientation you want before
          placing it on the Viton, as you will likely not be able to slide the
          acrylic against the Viton once it is placed.

        - You can use the inside edges of the Viton to guide the placement of
          the acrylic along that dimension, but all other edges will extend
          slightly beyond the Viton, so they will not be useful for alignment.
          Ultimately, it is just important that the alignment of all the holes
          is OK between these two layers, just enough so you can get a screw
          through.

        - Same note on symmetry / orientation as with the Viton layers.

    - Push all the 5/8" long 8-32 button head screws into the holes.

        - You should not have to force them, but it is normal for there to be a
          little resistance pushing them into the holes, if the layers are
          slightly misaligned as the Viton is rubbing against the screw.

    - Tighten the screws down, after re-adjusting alignment between the white
      and yellow layers.

      - If available, put the clutch torque limiter on the lowest
        torque setting, and put in each screw until the limiter engages.

      - Try to use a consistent speed with the screwdriver, though it likely
        does not matter much.

      - Either start from one side or start from the center and work outwards.

    - Place the ceiling back on, such that the slightly shorter contact section
      (~11.5mm vs ~13.5mm) is closest to the side of the floor circuit board
      with the large 25 pin D-sub connector.

        - If the ceiling has already been used for a while, the longer contact
          should have deeper grooves from sliding wear with the contacts on the
          floor circuit board.

        - The reason for this, is that this shorter contact stops just short of
          riding up onto the gold spring-loaded connector during the loading
          process, and if it were not as short as it is, this position would
          line one set of vent holes up with the chambers, so flies could
          escape.

        - Place white Delrin rails and secure with 2 to 3 1/2" long 6-32 screws
          per rail. Place the screws such that, when the ceiling is in its
          final position, with all electrodes centered and each contact engaged
          with one set of spring connectors, the screws are next to part of the
          wider part of the ceiling, and not further out, toward the contacts.

          - This is because the rails will warp, not applying consistent
            pressure, if they aren't pushing directly down on the main flat edge
            of the ceiling.

4. Load the flies.

    - Prepare any odor dilutions before this step, and have the odor vials in
      the vial holders, just disconnected from the valves. You may connect the
      vial outlets to the odor manifold at this point if you'd like.

    - Set the chamber on a flat surface in front of you, oriented so the 25 pin
      D-sub connector is away from you.

    - Tighten the rail screws down as far as you can, such that the ceiling can
      slide back and forth along its long axis without much friction.

      In the topmost position, the shorter contact should stop against the side
      of the top spring-loaded connector, without sliding up on to it. If it
      slides up onto it, then the two rail screws closest to that connector
      should probably be a little tighter.

      The bottom ceiling contact should be depressing the bottom spring
      loaded connector just slightly. No space around the edge of the board
      should be wide enough for a fly to escape, but if there is only space
      along the bottom edge, and the you start from the top, you can leave the
      bottom screws a little loose until you get to the bottom, which will
      extend the life of the bottom contact slightly.

    - Starting from the top, use a fly aspirator to load flies into the
      chambers, one at a time, using the following motion:

      - Suck a fly into your aspirator. If you are only using one gender, and
        you have not already sorted your flies by sex, determine the gender of
        your fly before deciding whether to reject (into a morgue or back into
        the vial) or use the fly. Try to only use as much suction as is
        necessary, because too much could damage the fly.

      - Line up your aspirator with the top hole of the chamber you want to
        load. Apply suction, as necessary, to keep the fly out of the vent hole
        until you are ready to load the fly.

      - When you are ready to load the fly, quickly slide the ceiling towards
        you until the far set of vent holes lines up with the chambers, just
        enough so that a fly can fit through the space. **This step and the next
        two must be performed quickly, so as to not let any flies that have
        already been loaded escape.**

        - It sometimes helps to watch the flies that have already been loaded to
          wait until they are away from the vent holes, to minimize the chance
          of them escaping when you load the next fly.

        - If you slide the ceiling down too far, the top fly might escape from
          the extra space you create.

      - Blow your fly in to the chamber, tapping the aspirator against the hole
        if the fly is stuck to some internal surface of the aspirator.

      - Quickly slide the ceiling back up into position, preventing any flies
        from escaping.

    - Once you have loaded all your flies, tighten the screws a little further,
      so that the flies will not be able to escape as your adjust the ceiling in
      the next step.

    - Use a screwdriver or other instrument to gently lift up the top ceiling
      contact from the edge, and push the ceiling board up onto the top
      spring-loaded connector. **Try not to damage the contact when doing so.**

    - Tighten down the rail screws to a little past finger tight. You are ready
      to load the chamber into the box now.

4. Setting up for the experiment.

    - Connect the outlets of the high flow mass flow controllers to the inlets
      on the humidifier bottles, if they are not already connected.

    - Place your odor vials in the odor vial holders, and connect their outlets
      to the odor inlet manifold, if they are not already.

      - **Be careful with the Luer input connectors on the odor manifold, as the
        threads are not deep enough to avoid stripping on their own.** You may
        need to brace these connectors with either your finger or some pliers /
        hemostats.

    - Place the loaded chamber into the box.
    
      - Tilt one side up (alternate to reduce side bias this may introduce),
      
      - Rest the down-tilted side against one of the support rails.
      
      - Lift the odor inlet tubing on the up-tilted side with your other hand,
        and rest the previously up-tilted side down on the support rail, with
        the odor inlet tubing out of the way. Then release the odor inlet
        tubing.

      - Connect the two odor inlet Luer locks to the Luer locks on the chamber.

      - Connect the D-sub connector from the shock delivery electronics to the
        D-sub connector on the chamber.

      - Close the chamber, by draping a darkout cloth over the front or
        any openings. Tuck the darkout cloth in by the sides of the box, taking
        car that it is not kinking or putting much pressure on any of the odor 
        tubing.

      - Just before you are ready to start your experiment, enable the power
        supply, by pressing the enable button on the left. A green LED should go
        on. **From this point on, take special care not to touch any of the
        electronics dealing with the shock delivery.** No LEDs indicating
        overcurrent / other fault conditions should go on.

      - See the main README in this repository for instructions on running the
        software.

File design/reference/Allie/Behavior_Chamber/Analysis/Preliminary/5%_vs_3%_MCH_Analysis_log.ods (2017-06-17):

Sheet: PI
Trial 1, against 5% MCH
Fly 1 |  |  | Fly 2 |  |  | Fly 3 |  |  | Fly 4 |  |  | Fly 5 |  |  | Fly 6 |  |  | Fly 7 |  |  | Fly 8
% | 3% MCH | 5% MCH | % | 3% MCH | 5% MCH | % | 3% MCH | 5% MCH | % | 3% MCH | 5% MCH | % | 3% MCH | 5% MCH | % | 3% MCH | 5% MCH | % | 3% MCH | 5% MCH | % | 3% MCH | 5% MCH
0.00% | 0 | 1 | 66.67% | 4 | 2 | 100.00% | 1 | 0 | 33.33% | 1 | 2 | 40.00% | 2 | 3 | 57.14% | 4 | 3 | 100.00% | 1 | 0 | 50.00% | 0 | 0
80.00% | 4 | 1 | 50.00% | 1 | 1 | 25.00% | 1 | 3 | 66.67% | 2 | 1 | 100.00% | 1 | 0 | 60.00% | 3 | 2 | 50.00% | 0 | 0 | 100.00% | 3 | 0
100.00% | 1 | 0 | 33.33% | 1 | 2 | 100.00% | 1 | 0 | 66.67% | 2 | 1 | 50.00% | 1 | 1 | 40.00% | 2 | 3 | 100.00% | 1 | 0 | 0.00% | 0 | 2
 |  |  |  |  |  | Pre-Conditioning |  |  |  |  |  | Immediate Post-Conditioning |  |  |  |  |  | 10 min delay post-conditioning
Where % = % decisions for 3% MCH 1st row = pre conditioning 2nd row = post conditioning, immediate 3rd row = post conditioning, 10 minute delay |  |  |  |  |  | Mean for 3% MCH |  |  | 55.89% |  |  | Mean for 3% MCH |  |  | 66.46% |  |  | Mean for 3% MCH |  |  | 61.25%
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

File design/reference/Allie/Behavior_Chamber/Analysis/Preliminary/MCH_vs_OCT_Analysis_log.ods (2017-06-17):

Top – Against 5% MCH; Key: Period 1 = Pre-training; 2 = Mock; 3 = Post training w/ 5% MCH; 4 = w/ 4% MCH; 5 = w/ 3% MCH
Bottom – Against 8% OCT; Key: Period 1 = Pre-training; 2 = Post training w/ 8% OCT; 3 = w/ 6% OCT; 4 = w/ 4% OCT
Fly 1 |  |  | Fly 2 |  |  | Fly 3 |  |  | Fly 4 |  |  | Fly 5 |  |  | Fly 6 |  |  | Fly 7 |  |  | Fly 8 |  |  |  | Mean |  | SEM
Period | Into MCH | Into OCT | Period | Into MCH | Into OCT | Period | Into MCH | Into OCT | Period | Into MCH | Into OCT | Period | Into MCH | Into OCT | Period | Into MCH | Into OCT | Period | Into MCH | Into OCT | Period | Into MCH | Into OCT |  | Entry into 5% MCH | Entry into 12% OCT | MCH | OCT |  |  | Trained Against 5% MCH | Trained Against 3% MCH | SEM Against 5% | SEM Against 3%
1 | 50% | 50% | 1 | 57% | 43% | 1 | 0% | 0% | 1 | 56% | 44% | 1 | 63% | 38% | 1 | 43% | 57% | 1 | 25% | 75% | 1 | 57% | 43% | Pre-Conditioning | 50.03% | 49.97% | 4.79% | 4.79% |  | Pre-Conditioning | 50.03% | 43.88% | 4.79% | 7.70%
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

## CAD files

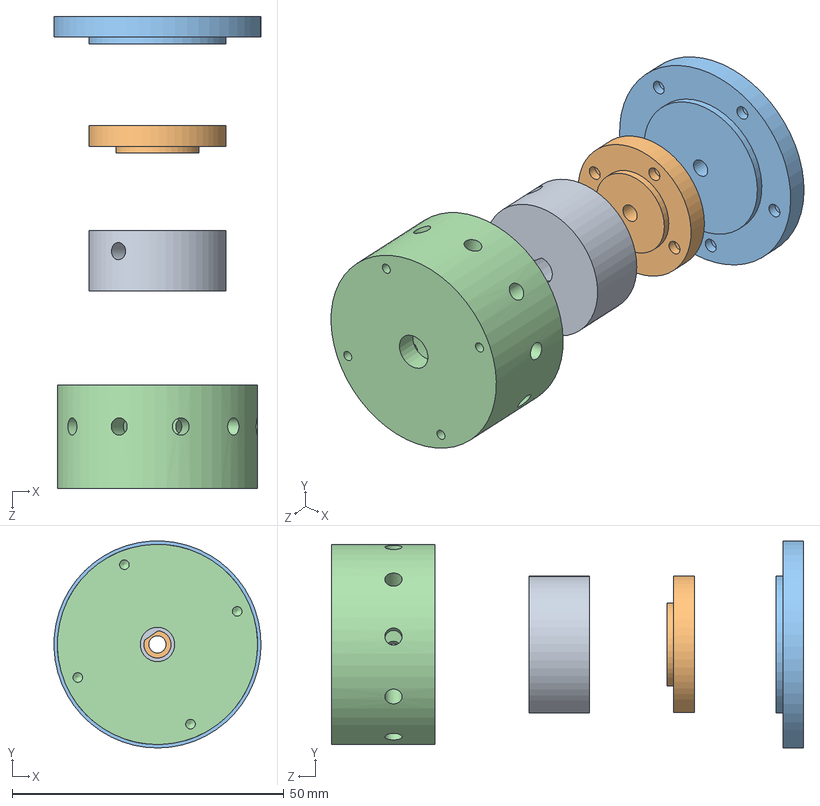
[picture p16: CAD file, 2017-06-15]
design/reference/Job-022-Flysorter/Flysorter.SLDASM
38.1 x 38.1 x 86.9 mm
InnerBase
InnerCap
OuterCap
OuterRing

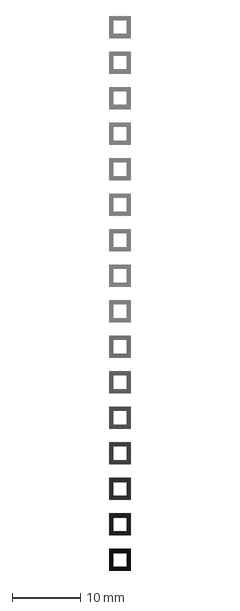
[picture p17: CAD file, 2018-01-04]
design/helpers/laser_etch_test_array.dxf
3.20 x 81.2 mm

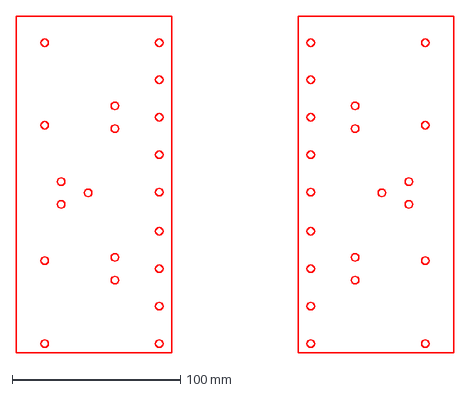
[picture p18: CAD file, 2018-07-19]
design/lasercut/exploded/pcb_side_gaskets.dxf
260.0 x 200.0 mm

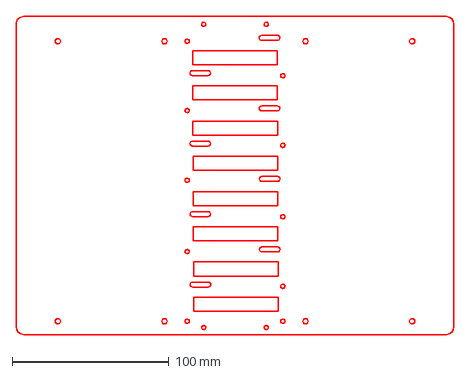
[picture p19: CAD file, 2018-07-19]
design/machined/tapped_metal_baseplate_dxf07.dxf
279.4 x 203.0 mm

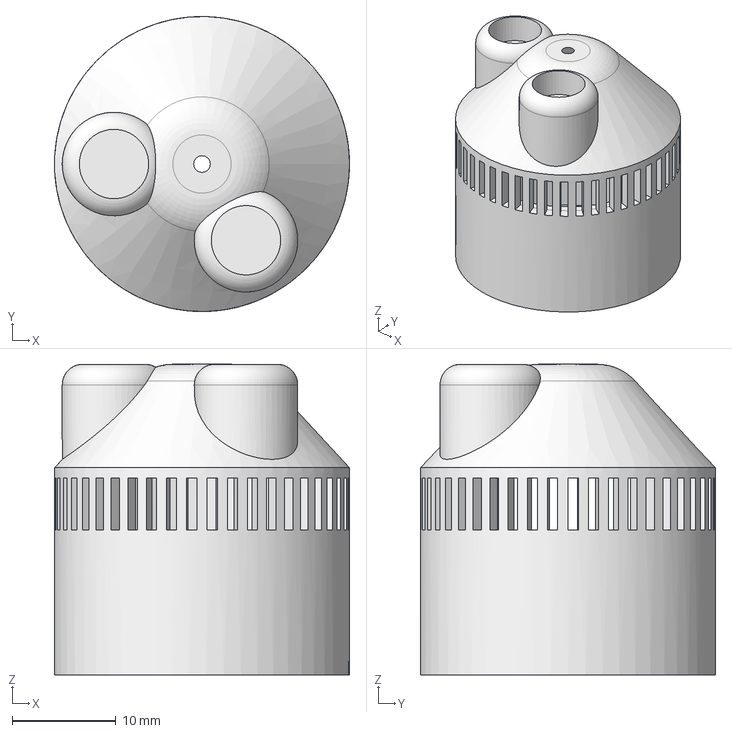
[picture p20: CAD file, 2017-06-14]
design/print/slotted_vial_to_funnel_adapter.fcstd
28.5 x 28.5 x 30.0 mm

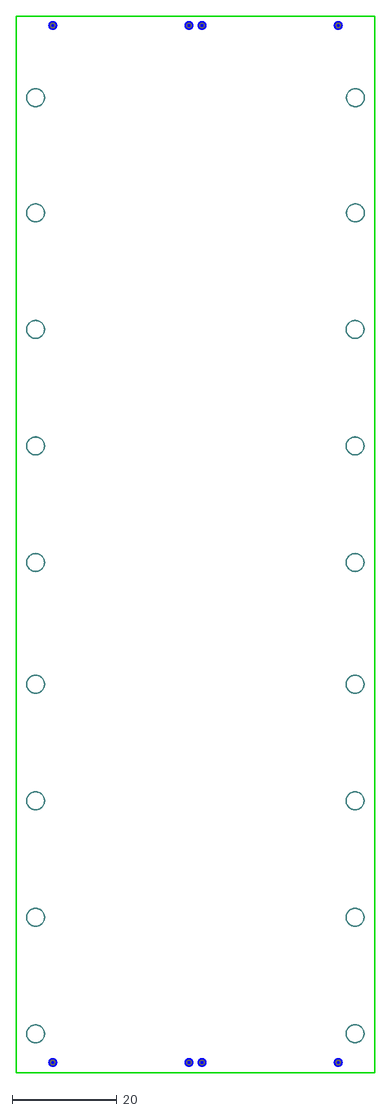
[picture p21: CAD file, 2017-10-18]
design/reference/Allie/Behavior_Chamber/Chamber_Design/PCB/Small_board.dxf
68.5 x 201.8

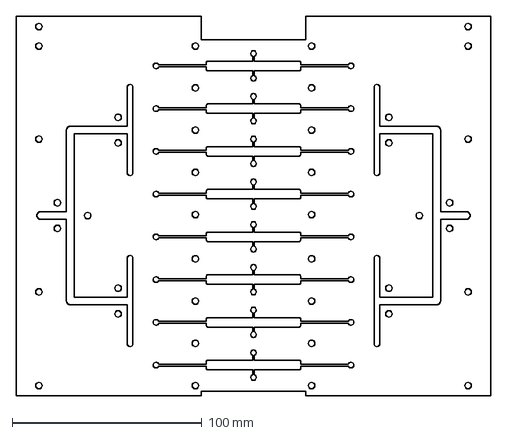
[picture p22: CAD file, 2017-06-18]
design/reference/Allie/dxfs/3.dxf
250.0 x 200.0 mm

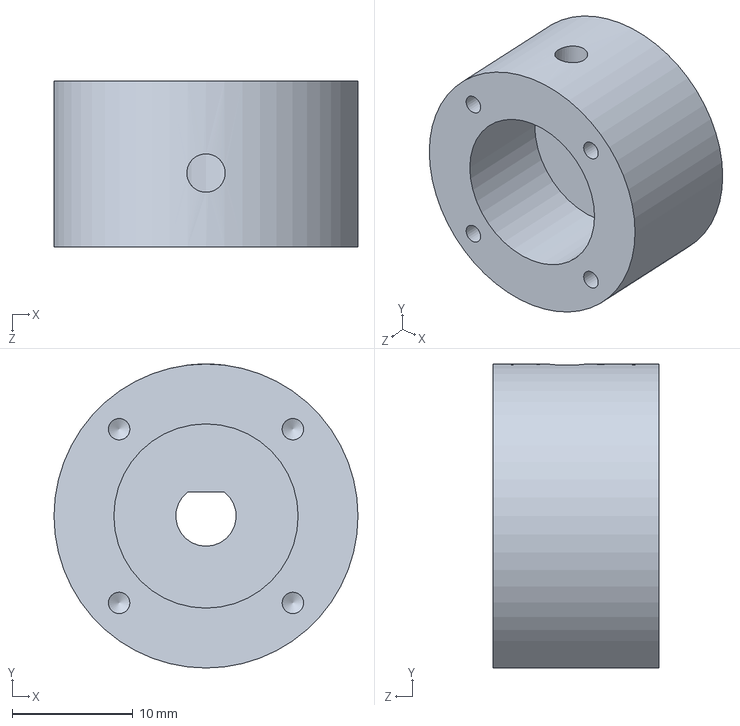
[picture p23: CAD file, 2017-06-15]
design/reference/Job-022-Flysorter/InnerBase.SLDPRT
25.1 x 25.1 x 13.7 mm

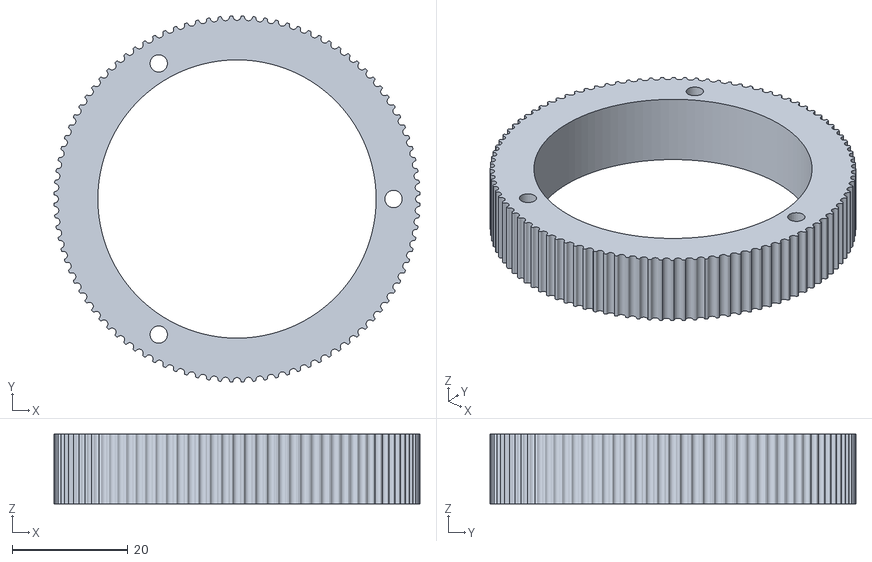
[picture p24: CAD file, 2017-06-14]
design/reference/vial_susan_pulley.stl
63.1 x 63.1 x 12.0

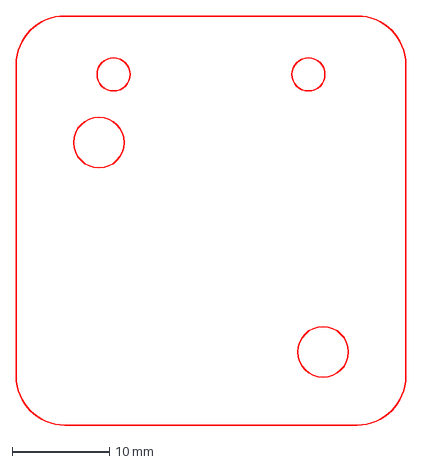
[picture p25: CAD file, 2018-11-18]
design/lasercut/maple_big_valve_mount.dxf
40.0 x 42.0 mm

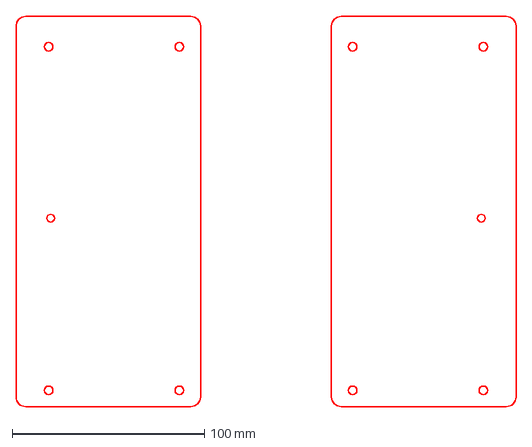
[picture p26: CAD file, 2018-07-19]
design/machined/top_acrylic_manifold_sides_dxf07.dxf
260.0 x 203.0 mm

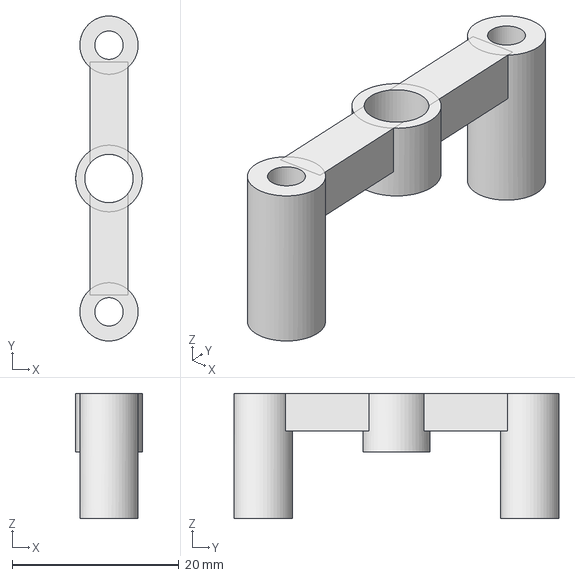
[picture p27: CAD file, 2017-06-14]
design/print/rough_tubing_support.fcstd
8.00 x 39.0 x 15.0 mm

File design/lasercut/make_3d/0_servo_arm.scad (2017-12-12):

color(c = [1, 1, 1, 0.2000000000]) {
	translate(v = [0, 0, 21.8282000000]) {
		dxf_linear_extrude(file = "../olfactory_shock_conditioning_chambers.dxf", height = 3.1750000000, layer = "0_servo_arm");
	}
}

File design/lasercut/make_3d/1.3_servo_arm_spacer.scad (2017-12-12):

color(c = [1, 1, 1, 0.2000000000]) {
	translate(v = [0, 0, 18.6532000000]) {
		dxf_linear_extrude(file = "../olfactory_shock_conditioning_chambers.dxf", height = 3.1750000000, layer = "1.3_servo_arm_spacer");
	}
}

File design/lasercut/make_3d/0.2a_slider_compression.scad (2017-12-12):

color(c = [1, 1, 1, 0.9000000000]) {
	translate(v = [0, 0, 21.8282000000]) {
		dxf_linear_extrude(file = "../olfactory_shock_conditioning_chambers.dxf", height = 1.5875000000, layer = "0.2a_slider_compression");
	}
}

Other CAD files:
design/lasercut/olfactory_shock_conditioning_chambers.dxf
design/reference/Allie/Allie/AutoCAD/Layers/PCB_insert.SLDPRT
design/reference/Allie/Behavior_Chamber/Chamber_Design/Layers/1.SLDPRT
design/lasercut/exploded/one_ver_of_toxic_layers_exploded.dxf
design/reference/Allie/Allie/AutoCAD/Layers/LED_side_small.SLDPRT
design/reference/Allie/Behavior_Chamber/Chamber_Design/Layers/2.SLDPRT
design/lasercut/make_3d/1.1_top_acrylic_manifold_sides.scad
design/lasercut/box_side.dxf
design/lasercut/ceiling_pcb_edges.dxf
design/lasercut/chamber_parts.fcstd
design/lasercut/exploded/pcb_side_gaskets_array.dxf
design/lasercut/floor_pcb_edges.dxf
design/lasercut/humidifier_bottle_brace.dxf
design/lasercut/humidifier_bottle_mount_bottom.dxf
design/lasercut/inside_plate_with_slots.dxf
design/lasercut/make_3d/1.2a_top_pcb_edges_and_routing.scad
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

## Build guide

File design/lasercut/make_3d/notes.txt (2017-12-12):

layers that are having problems in conversion through scad:
-servo_arm
-yellow_manifold

-6.2 vacuum trap tops will probably have issues, but it seems it wasn't generated,
 and i'm not sure why?
	-may want to handle all layers w/ blue separately?
	-break in to two layers?

-also, i'm pretty sure it is a block definition (re, the hatch, splines) that is scaring openscad, even if it isn't used in current layer

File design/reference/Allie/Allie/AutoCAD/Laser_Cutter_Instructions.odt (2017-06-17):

Laser Cutter Instructions:

1. Turn on laser cutter (switch on side)
2. Turn on compressed air (orange nozzle) about ¼ turn clockwise
3. Rest beam focuser (on front of machine) onto laser and press focus on keypad
4. Move focus up and down until it is just touching the material you want to cut
5. For 1/8 inch acrylic press up button 3 to 4 times to focus beam on centre of material
6. Remove focus tool
7. Press reset
8. On computer: click print: properties. Set to 24x18
9. Select vector
10. Set freq to max and set cutting speed to 16?
11. Press OK and print
12. Turn middle valve from 0 to FWD
13. Hit GO on the machine
14. If it doesn’t cut all the way through material, use a slower speed

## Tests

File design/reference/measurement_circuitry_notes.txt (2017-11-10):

from Daniel Winker (personal communication):
and it says R0 > 160k for power dissipation, but minimum input resistance to the opamp seems to be ~1MOhm, so R0 < 1Meg

so the source (output) resistance and input resistance form a resistive divider. If they're equal, the voltage is halved. etc.
That's where the input resistance >> output resistance comes from

The approach to ovp seems reasonable. I've used the same thing to protect from inductive kickback, and I've always sort of wondered about the other stuff on the supply line..

I guess the basic idea is, as long as the supply circuit is pretty good, and the current is relatively low, then Vcc won't change much. But if you had like, 200V @1 Amp you would need a beefy regulator.

The 1 Meg input resistance was sort of a pessimistic estimate

Looking at 'Input Current with Input Voltage High' (in the datasheet)

max is +/-1uA, so I just kind of picked 1V so V/I = 1 Meg.

More realistically, it says VA = 2.4V or 15V, so if it can go to 15V and 1uA, then that's 15 Megs

and it says typical is 0.001 uA, so 15V -> 15,000 Megs which is...crazy. (It does say low leakage, so I guess they got that down)

The reason I went with 1 Meg though, is because the lower limit for that resistor was 160k, so it doesn't need to be super huge

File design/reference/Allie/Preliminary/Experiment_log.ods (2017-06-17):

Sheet: Conditions
Run Number | Fly batch | Training Against | Conc MCH | Conc OCT | Vol MCH | Vol OCT | Mass Paraffin w/ MCH | Mass Paraffin w/ OCT | Pre-Conditioning Testing | Conditioning | Post-Conditioning Testing | Flow Rates | Use 4ml of solution for each | Conversion of 1.6g=2ml
- | 1 | MCH | 5% | 12% | 200ul | 480ul | 3.04g | 2.82g | MCH left, OCT right, time: 2mins, valves: 1001 | OCT 1 min both sides valves: 0101, MCH+shock 12x 1 min both sides valves: 1010, training x2 | MCH left, OCT right, time: 2mins, valves: 1001 | HFC: 480ml/min; Odor: 320ml/min | Valve settings are in binary: 1 = on; 0 = off, for valves 1,2,3,4
- | 2 | MCH | 5% | 12% | 200ul | 480ul | 3.04g | 2.82g | MCH left, OCT right, time: 2mins, valves: 1001 | OCT 1 min both sides valves: 0101, MCH+shock 12x 1 min both sides valves: 1010, training x2 | MCH left, OCT right, time: 5mins, valves: 1001 | HFC: 480ml/min; Odor: 320ml/min
0 | 3 | MCH | 5% | 12% | 200ul | 480ul | 3.04g | 2.82g | MCH left, OCT right, time: 2mins, valves: 1001 | OCT 1 min both sides valves: 0101, MCH+shock 12x 1 min both sides valves: 1010, training x2 | MCH left, OCT right, time: 5mins, valves: 1001 | HFC: 480ml/min; Odor: 320ml/min
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

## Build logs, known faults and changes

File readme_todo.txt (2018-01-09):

installation

1.
- TODO include script to automate all of this (except maybe Arduino upload)
- TODO test sufficiency of ros-kinetic-ros-base. May need `ros-kinetic-ros-desktop`, or at least a few more packages.

2.
- TODO ROS install file?

manufacture

See bill of materials [TODO]()
actually describe manufacture...

running an experiment
requirements
TODO include portion (maybe wiki?) on setting parameters for ROS launch files.

TODO clarify which camera parameters are read by launch files / give options / instructions for other cameras

TODO example usb camera parameter file? do i use one now?

offline tracking
definition of valid directory:
- TODO is compressor_rois* actually required, or can it be recovered from other files? which?

TODO test file + directory options still work in retrack_ros script (was using env var / id most recently)

TODO check expectation relative to DATA_DIR
TODO move it before directory arg? set in a computer specific config

TODO name multi_tracker/retrack_ros something to clarify which type of experiment it is to be used for, or give it an argument to indicate when this type of tracking should be used

copying data...

TODO include instructions on how to setup dedicated SSH keys for rsync, to automate the transfer
TODO include instructions on how to automatically start analysis / tracking after transfer, once polished

analysis
move most of this to a readme within the analysis dir and link there? wiki?

known bugs / workarounds

TODO identify / fix root cause / confirm it is no longer an issue
wasn't there a different command i used to kill all python for some reason? subprocesses?

move explanations of warnings / errors to another section? re-order?
kind of breaks up flow, as is.

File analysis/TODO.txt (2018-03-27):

split metric change charts up by which odor was reinforced
(in addition to current plots)

store notes on age, density (?), time of day, time of starvation
(and generate information re: which odor was trained) to plot
metric changes for each of these as well, for debugging

instead of saying "nan" if metric cannot be computed, say "n/a"? (in notes
embedded in plots)

also group traces by experiment, to more easily view problems specific to
experiments

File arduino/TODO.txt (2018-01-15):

maybe break this stuff out in to its own repo (for sure, the shock library)
	-and subtree / module it? or just keep separate?
	-I think I want to subtree multishock library
	 -should also include automation for setting up subtree / pushing to it

(might make some people think this is arduino code for stimulus here, as is)
-include it as an example somehow? (automatically, in arduino library)

3. (maybe using one of the makefile solutions) put test code, using the library,
   in the same level as lib / libraries (this directory)
   -include instructions on how to build it (reference install if want to use 
    arduino IDE, because stupid lack of support for sketch-relative library 
    includes)
   -maybe fix Arduino sketch-relative library imports and pull request?
    , or otherwise determine why that hasn't been done yet

4. maybe also try to get it in Library Manager and reference that option
5. include a zip of it?

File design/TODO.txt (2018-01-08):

-redesign frame to eliminate need for flat inside corner connectors
 (the ones with the nubs that are cheaper, particularly for 20mm)

-redesign side panelling to snap on? magnets?

-redo LED mounts to not require / benefit from milling mounting slots

-redo bottom of enclosure s.t. does not depend on extending to table
 surface for being light proof

-better light proof entries for wire / tubing than what I use now
 (gaffers tape)

-BOM and instructions!!

-are risers still required for mounting chambers flush?
 -redo to eliminate need for them if so
 -otherwise include design files for them

-add designs showing mounting slots in aluminum sheet, where to put LEDs,
 and maybe add holes for possibly mounting a heatsink
	-good way to attach LED strips to it? get thermal paste / epoxy?
	 does their sticky coating null that?

-is way LEDs are wired up likely to cause illumination / temperature gradient?

-what's an appropriate way to power them? do people just use constant current
 drivers to achieve more brightness or what? control? wouldn't higher voltage
 have same effect of constant current or not?
	-if i'm going to stick with wall wart, filter output?
	 (i.e. is the power supply, camera, or the LEDs the most likely reason
	  K sometimes has lighting flickers? more than the one?)

-some way to basically make this a one click order thing? / useful BoM format?

-include a script with calculations related to the optics
	-e.g. lenses, sensor size / pixels, fly size / pixels, distances, etc
-test new cameras when they come
 (M7 lens mount seems more common now, so cheaper, but board 
  seems almost identical)
 -possible problems with current camera / driver?

-find source for darkout cloth we had -> possibly cheaper replacement. sail?
 -> add to bom

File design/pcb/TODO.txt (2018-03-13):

routing to L/R electrodes in custom footprint may be difficult b/c the origin of
that pad (might?) overlap w/ the clearence of the center electrode
-fix and check

******
test jig to measure + verify gate voltages are being set correctly
(to check for both hw and sw issues) or all embedded?

either w/ jumper or power switch of some kind, allow for connection between
at least iso_5v and HV (to allow for switching mosfets to produce current ->
measure voltage -> test / determine switch state <-> fet bit mapping)
-perhaps also allow for HV to one of the shift register outputs?
-power switch would be nice... (it should get input from one of the unused shift
 register outputs, and perhaps also be jumper configurable in either direction)
 because then board could basically test itself

-what else could be automatically tested? transistor to bypass instrumentation
 amplifier?
 -worth it?
 couldn't really electrically select bypass of isoamp... relay?
 probably too likely to lead to someone breaking isolation

-automatic test of FET <-> demux states mapping should also report possibly
 broken FETs

-might want to move enable bit to end of s.r., or 7th bit, to allow for same
 firmware for boards with 6 bits of channels (would make converting to
 demux_states (as-is, 5 bits) more tricky though...)

-bring reset button up on to shield (optional population)
******

decide whether to keep shield sch / footprint lib above, and then make sure
versions in project dir are current if deleting old masters

resolve conflicts between "rescue" (kicad dev v4->v5) derived project specific
schematic libraries with same-level schematic library i had made before
-PARTS SHOULD ONLY BE IN ONE OR THE OTHER, SAME-LEVEL IF SHARED...

make silkscreen prettier on shield board
	-(better) orientation information for FETs and diodes
	-less overlap / more consistency in orientation
	-larger github reference
	-isolation barrier depiction
	-warnings / descriptions of test points / bypass

don't have zone on B.Cu overlap with any metal parts on arduino
	-other ways to improve isolation?
tell people to assemble circuit board shortest components to tallest
	-maybe with some exceptions?
		-any stuff you can bend long pins on?
	-so that those components can be flush on the surface during assembly

reverse voltage protection on hv power supply

maybe get all DIP sockets as the kind that have pins bent in alternating
directions, for easier soldering?

bigger holes for connector to power supply! if i don't find a better connector
or integrate the high voltage supply

some kind of autogenerated instruction at least grouping components by type?
(kicad seems to support some instances of this, just pick one easy to automate?)

add LEDs to indicate:
-which fly is getting shocked (easiest, should be fine to split SR output)
-which fly is getting measured (easy: just show representation used, hard:
 convert to above) though the hard would be more quickly interpretable, other
 would require lookup table. could silkscreen table on to board?

-pull them out to the edge, or just put on the main face of the board somewhere?
-good parts for edge LED arrays?

-good interface for testing?
-what all do i want to test?
	-just put reference I (through) / R / V (across) each channel?
	-ovp?
	-reverse voltage protection (non-existant now)?

-detect whether mosfets are installed correctly?
	-why did i want to do this again? hoping to get rid of zeners?

-auto fill git repo information into version field on pcb during plotting

-make one version of shield board that is all surface mount?
	-would be interested in cost difference
-change diodes to through hole on existing through hole board

-space 10uF caps further from ICs (just a little)

-put in headers last
-slightly more space for measurement / maybe dissiation resistor (lengthwise)
-indicate zener direction

-account for all current. maybe shut down and indicate if over current
 (could use oscillator enable pin on DCP020507)
-maybe sense lt1118 temperature and do the same? i assume it is most likely to
overheat?

-include jumper for bridging iso-gnd with gnd, for testing? warn?
 maybe a single female pin for iso-gnd

-include (optional?) power jack (with / in-place of DCP020507 or equiv,
 depending on whether we can get isolation guarantee or not w/ external) +
 config switch
-even if not to avoid going over USB current limits (which it seems we would)
 , maybe disable 5-to-7 volt converter if arduino is just on USB power for
 easier programming (without risking overcurrent / brownout / etc. during
 programming)?
 -typical implementation?
-switch setting to disconnect power during programming?

-do i want to protect against ICs coming loose in sockets w/ extra
 pull-up/downs?

-TODO label which isolators control what, label s.r.s the same
and say which # chambers s.r.s control / which other pins, and label those too

-male(?) pins to isognd/5v for easier testing of subcircuits on a breadboard

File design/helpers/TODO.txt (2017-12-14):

remember to git subtree push / script it
git subtree push --prefix=design/helpers/kicad_holes hole_fixing_plugin master

are there existing plugins to take input of component coordinates or something and place
components?
	-maybe turn make_board into something like that?

maybe also add support to existing arraying tools s.t. a route between two can be copied to 
others?
	-commercial ways this is done? seems ugly to not have it repeated
	-alternatives w/in kicad? just copy somehow?
	-maybe also allow for things like flipping every other (which i might need)
	 to avoid mounting holes and stuff

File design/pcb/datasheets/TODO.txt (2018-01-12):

maybe include Uno + Mega linear regulators, to indicate operating temperature range and current
limits / worst case voltage drops, etc

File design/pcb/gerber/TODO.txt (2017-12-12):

generate interior holes as npth drill files, not (exclusively?) as part of edge cuts

kicad plotting automation?

(upload to FreeDFM / other?) scripts

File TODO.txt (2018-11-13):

- ***immediately restrict image to tight bounding box of all ROIs***
  - to save computational work

- undo/redo when labelling for analysis_rejects.yaml

- add facilities for testing valves before trials.
	 - service?

- pause until user signals they have connected everything before starting
  acquisition? just run trial structure generator in advance as before?

- FIX STIMULUS PARAMETER SAVING (FROM TRACKER, OR REPEAT IN THIS LAUNCH) WHEN
  TRACKING CONCURRENTLY

- copy stimulus parameters to retracked directory (maybe any pickle files?)

- only start shock after the fly has experienced the odor

- include scripts to help automate setup of key pair for secure rsync and
  include optional path in probably save_data_to_hdf5, maybe another data saving
  node, to copy data via rsync in shutdown hook
- should i start retracking locally under any circumstances? (leaning towards
  no, if aiming for max experiment uptime)

- why were some experiments missing roi_NX.yaml files, but not others?

- install script (rosinstall?) for tracking and everything
  (w/ verified versions of dependencies!)
  - zip up all code and host / backup?
- maybe make a subset of the code installable for analysis w/o ROS
  - at least another install script, maybe pip?

-add configuration to run a trial, but w/ no odors, or change the odor
 configuration s.t. it's easier to have the software realize nothing you don't
 want to connect anything (for troubleshooting experiments)

- some kind of central (maybe Github repo based) collection of various
  parameters

- orient plots s.t. the starting odor is always on the same side?
  - one reason to not do this, is it would make it harder to see spatial
    bias by eye
  - could also just group them by orientation, then which odor was shocked,
    and then whether the shocked odor came first? or something like that?

- interface w/ MFCs, if only to verify target flow has been achieved, and err
  otherwise

- closing gracefully if ctrl-c-ing at all points in experiment start? roi window
  seemed it might have been causing a hang until that was also exited?

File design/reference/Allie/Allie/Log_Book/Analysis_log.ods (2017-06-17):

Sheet: PI
Trial 1, against 5% MCH
Fly 1 |  |  | Fly 2 |  |  | Fly 3 |  |  | Fly 4 |  |  | Fly 5 |  |  | Fly 6 |  |  | Fly 7 |  |  | Fly 8
% | 3% MCH | 5% MCH | % | 3% MCH | 5% MCH | % | 3% MCH | 5% MCH | % | 3% MCH | 5% MCH | % | 3% MCH | 5% MCH | % | 3% MCH | 5% MCH | % | 3% MCH | 5% MCH | % | 3% MCH | 5% MCH
0.00% | 0 | 1 | 66.67% | 4 | 2 | 100.00% | 1 | 0 | 33.33% | 1 | 2 | 40.00% | 2 | 3 | 57.14% | 4 | 3 | 100.00% | 1 | 0 | 50.00% | 0 | 0
80.00% | 4 | 1 | 50.00% | 1 | 1 | 25.00% | 1 | 3 | 66.67% | 2 | 1 | 100.00% | 1 | 0 | 60.00% | 3 | 2 | 50.00% | 0 | 0 | 100.00% | 3 | 0
100.00% | 1 | 0 | 33.33% | 1 | 2 | 100.00% | 1 | 0 | 66.67% | 2 | 1 | 50.00% | 1 | 1 | 40.00% | 2 | 3 | 100.00% | 1 | 0 | 0.00% | 0 | 2
 |  |  |  |  |  | Pre-Conditioning |  |  |  |  |  | Immediate Post-Conditioning |  |  |  |  |  | 10 min delay post-conditioning
Where % = % decisions for 3% MCH 1st row = pre conditioning 2nd row = post conditioning, immediate 3rd row = post conditioning, 10 minute delay |  |  |  |  |  | Mean for 3% MCH |  |  | 55.89% |  |  | Mean for 3% MCH |  |  | 66.46% |  |  | Mean for 3% MCH |  |  | 61.25%
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

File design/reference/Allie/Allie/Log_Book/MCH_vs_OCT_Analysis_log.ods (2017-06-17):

Top – Against 5% MCH; Key: Period 1 = Pre-training; 2 = Mock; 3 = Post training w/ 5% MCH; 4 = w/ 4% MCH; 5 = w/ 3% MCH
Bottom – Against 8% OCT; Key: Period 1 = Pre-training; 2 = Post training w/ 8% OCT; 3 = w/ 6% OCT; 4 = w/ 4% OCT
Fly 1 |  |  | Fly 2 |  |  | Fly 3 |  |  | Fly 4 |  |  | Fly 5 |  |  | Fly 6 |  |  | Fly 7 |  |  | Fly 8 |  |  | Mean |  | SEM
Period | Into MCH | Into OCT | Period | Into MCH | Into OCT | Period | Into MCH | Into OCT | Period | Into MCH | Into OCT | Period | Into MCH | Into OCT | Period | Into MCH | Into OCT | Period | Into MCH | Into OCT | Period | Into MCH | Into OCT | MCH | OCT | MCH | OCT
1 | 50% | 50% | 1 | 57% | 43% | 1 | 0% | 0% | 1 | 56% | 44% | 1 | 63% | 38% | 1 | 43% | 57% | 1 | 25% | 75% | 1 | 57% | 43% | 50.03% | 49.97% | 4.79% | 4.79%
2 | 50% | 50% | 2 | 50% | 50% | 2 | 0% | 0% | 2 | 58% | 42% | 2 | 41% | 59% | 2 | 50% | 50% | 2 | 40% | 60% | 2 | 50% | 50% | 48.50% | 51.50% | 2.35% | 2.35%
3 | 25% | 75% | 3 | 25% | 75% | 3 | 0% | 0% | 3 | 33% | 67% | 3 | 38% | 63% | 3 | 0% | 100% | 3 | 33% | 67% | 3 | 50% | 50% | 29.17% | 70.83% | 5.82% | 5.82%
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

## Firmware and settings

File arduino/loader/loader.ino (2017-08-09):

#include <math.h>
#include <Servo.h>
#include <EEPROM.h>

// only one vacuum solenoid, and a few rotary switches redirecting the flow
#define VACUUM_VALVE      45
#define SORTER_STEP       53
#define SORTER_SLEEP      51
#define EXIT_SORTER_STEP  49
#define EXIT_SORTER_SLEEP 47
#define STEPDRIVER_PULSE_MS   5
#define FULL_STEPS_PER_REV    200
#define MICROSTEPPING         8
#define SORTER_POSITIONS      10
#define SORTER_ALIGNMENT_OFFSET 30

// TODO if vacuum is too weak to suck flies out, divided across 8 chambers
// may need to have a 3rd sorter, not linked to the first two
// (and probably a mutually sealed position for the existing two sorters)

// input sorter: unused position
// output sorter: all conditioning chambers -> water vacuum trap -/-> house vac
// postions in range [0,9]
#define SEALED_SORTER_POSITION   9
#define SORTER_FAIL_STATE (byte) -1
//remaining positions will deal with vacuum traps

#define SERVO_WAIT_TIME_MS   2000
#define TRAP_VALVE_TIME_MS   6000
#define EGRESS_VALVE_TIME_MS 5000

#define NUM_TRAPS            8

// dolly can be 43 if using
#define ENTRY_CONTROL    39
#define EGRESS_SLIDER    41
#define FIRST_TRAP       23

#define ENTRY_OPEN       88
#define ENTRY_BLOCKED    96

#define FLY_ENTRY_SENSOR       A0
#define SORTER_PRESSURE_SENSOR A1

// (degrees)
#define BLOCKED    130
#define OPEN       140

#define EXPERIMENT 132
#define EGRESS     147

// TODO if i continue trying to attach horns on one edge of the mounting plate
// i may want to move them to an intermediate position (maybe at old delta of 15)
// between ready and open positions (closer to ready)
#define TRAP_READY 65
#define TRAP_OPEN_DELTA  55
#define TRAP_ATTACH_DELTA 5
#define TRAP_INTERMEDIATE_DELTA 15

#define TRAP_EXIT_THRESHOLD 800

/********************************************************************/
/* set this to true once you have attached the servo plate          */
#define SERVO_PLATE_ATTACHED true
#define ALIGN_SORTER true
/********************************************************************/

typedef boolean (*function)();

// doing it this way limits maximum range i could use by half
// but i don't need that much angular range on the servos
const int left_trap_open = TRAP_READY - TRAP_OPEN_DELTA;
const int right_trap_open = TRAP_READY + TRAP_OPEN_DELTA;
const int left_trap_attach = TRAP_READY - TRAP_ATTACH_DELTA;
const int right_trap_attach = TRAP_READY + TRAP_ATTACH_DELTA;
const int left_trap_intermediate = TRAP_READY - TRAP_INTERMEDIATE_DELTA;
const int right_trap_intermediate = TRAP_READY +
TRAP_INTERMEDIATE_DELTA;

Servo dolly, entry, egress;
Servo trap_servos[NUM_TRAPS];
int trap_servo_pins[NUM_TRAPS];

const int egress_servo_eeprom_idx = NUM_TRAPS;
const int entry_servo_eeprom_idx = NUM_TRAPS + 1;
const int dolly_servo_eeprom_idx = NUM_TRAPS + 2;
const int sorter_eeprom_idx = NUM_TRAPS + 3;

// be careful if this doesn't divide evenly (best to make it do so)
const int num_steps = MICROSTEPPING * FULL_STEPS_PER_REV;
const int steps_per_pos = MICROSTEPPING * FULL_STEPS_PER_REV / SORTER_POSITIONS;
unsigned int current_steps = 0;

// TODO remove
// pins these servos are on
//const unsigned char egress_slider = 2;
//const unsigned char trap1 = 8;

// TODO consider renaming full / fly_left for readability
boolean full[NUM_TRAPS];
boolean fly_left[NUM_TRAPS];
int trap_exit_sensors[NUM_TRAPS];

boolean sorter_sleeping;

void wait_for_char() {
  Serial.println("Send any character when you are ready.");
  while (!Serial.available()) { ; }
  while (Serial.available()) {
    Serial.read();
  }
}

void write_servo_pos_to_eeprom(int idx) {
  Servo s = trap_servos[idx];
  byte pos = (byte) s.read();
  // EEPROM addresses are one byte apart
  EEPROM.write(idx, pos);
}

void move_servo(Servo s, int pin, int deg, int idx) {
  s.attach(pin);
  s.write(deg);
  delay(SERVO_WAIT_TIME_MS);
  s.detach();
  if (idx != -1) {
    write_servo_pos_to_eeprom(idx);
  }
}

void move_servo_smoothly(Servo s, int pin, int deg, int duration_ms, int idx) {
  s.attach(pin);
  // assumes last wrote position is correct. requires minimum delay.
  int start_theta = s.read();
  int curr_theta = start_theta;
  // TODO no abs weirdness here (see docs comment about functions inside)?
  int dir = (deg - curr_theta) / abs(deg - curr_theta);
  int interval = duration_ms / abs(deg - start_theta);

  while (curr_theta != deg) {
    curr_theta += dir;
    s.write(curr_theta);
    delay(interval);
  }
  
  //delay(SERVO_WAIT_TIME_MS);
  s.detach();
  if (idx != -1) {
    write_servo_pos_to_eeprom(idx);
  }
}

void move_servo(Servo s, int pin, int deg) {
  move_servo(s, pin, deg, -1);
}

void move_servo_smoothly(Servo s, int pin, int deg, int duration_ms) {
  move_servo_smoothly(s, pin, deg, duration_ms, -1);
}

// TODO make timer based w/ global update if necessary
void move_servo(int idx, int deg) {
  Servo s = trap_servos[idx];
  int pin = trap_servo_pins[idx];
  move_servo(s, pin, deg, idx);
}

void move_servo_smoothly(int idx, int deg, int duration_ms) {
  Servo s = trap_servos[idx];
  int pin = trap_servo_pins[idx];
  move_servo_smoothly(s, pin, deg, duration_ms, idx);
}

// should prevent servos from jumping around if the program stops
// when they are in a different position than the first position
// they will be sent to upon restarting
void correct_servo_positions() {
  for (int i=0;i<NUM_TRAPS;i++) {
    byte pos = EEPROM.read(i);
    Servo s = trap_servos[i];
    // shouldn't actually require moving, if servo wasn't moved since last saved position
    // and if the move to the last saved position was successfully completed
    // BUT this will make remind the Arduino Servo library where all the servos are
    s.write((int) pos);
  }
}

void open_entry() {
  move_servo(entry, ENTRY_CONTROL, ENTRY_OPEN);
}

void block_entry() {
  move_servo(entry, ENTRY_CONTROL, ENTRY_BLOCKED);
}

void ready_trap(int trap_num) {
    move_servo_smoothly(trap_num, TRAP_READY, SERVO_WAIT_TIME_MS);
}

void release_fly(int trap_num) {
  if (trap_num < NUM_TRAPS / 2) {
    move_servo_smoothly(trap_num, left_trap_open, SERVO_WAIT_TIME_MS);
  } else {
    move_servo_smoothly(trap_num, right_trap_open, SERVO_WAIT_TIME_MS);
  }
}

void attach_servo_walkthrough() {
  // TODO how to actually only start when serial connection is "opened", if that is even detectable
  while (!Serial) { }
  Serial.println("Positioning servos for horn attachment...");
  Serial.println("Attach each horn as close to parallel to the edges of the mounting plate as possible.");
  for (int i=0;i<NUM_TRAPS;i++) {
    if (i < NUM_TRAPS / 2) {
      Serial.println("left. going to " + String(left_trap_attach));
      move_servo(i, left_trap_attach);
    } else {
      Serial.println("right. going to " + String(right_trap_attach));
      move_servo(i, right_trap_attach);
    }
  }
  
  wait_for_char();
  for (int i=0;i<NUM_TRAPS;i++) {
    if (i < NUM_TRAPS / 2) {
      move_servo(i, left_trap_intermediate);
    } else {
      move_servo(i, right_trap_intermediate);
    }
  }
  Serial.println("Now bolt the servo plate to the main maze assembly.");
  wait_for_char();

  move_servo(ENTRY_CONTROL, ENTRY_BLOCKED);
  Serial.println("Attach entry control servo horn covering the entry...");
  wait_for_char();

  move_servo(ENTRY_CONTROL, ENTRY_OPEN);
}

void test_servos() {
  Serial.println("Testing servos...");
  Serial.println("Each trap to ready position...");
  for (int i=0;i<NUM_TRAPS;i++) {
    Serial.println(i);
    ready_trap(i);
  }

  wait_for_char();
  Serial.println("Each trap to open position...");
  for (int i=0;i<NUM_TRAPS;i++) {
    Serial.println(i);
    release_fly(i);
  }
  wait_for_char();
  Serial.println("Entry control servo to open position...");
  move_servo(entry, ENTRY_CONTROL, ENTRY_OPEN);
  wait_for_char();
  Serial.println("Entry control servo to blocked position...");
  move_servo(entry, ENTRY_CONTROL, ENTRY_BLOCKED);
}

// TODO what was cause of lurching on restarting stepper? these didn't 
// seem to fix the problem...
void unsleep() {
  if (sorter_sleeping) {
    digitalWrite(SORTER_SLEEP, HIGH);
    sorter_sleeping = false;
  }
}

void resleep() {
  if (!sorter_sleeping) {
    digitalWrite(SORTER_SLEEP, LOW);
    sorter_sleeping = true;
  }
}

// could play with trailing delay
void stepper_driver_pulse(int pin) {
  digitalWrite(pin, HIGH);
  delayMicroseconds(2);
  digitalWrite(pin, LOW);
  delay(21);
}

// TODO might be hard to make non-blocking
// might also consider only switching ENBL on at beginning
// DIR is only set once (not switching directions should make backlash less of a 
// problem)
void position_sorter(unsigned int goal_pos) {
  unsigned int goal_steps = goal_pos * steps_per_pos;
  // if move gets interrupted, we will need to re-align sorter next start
  EEPROM.write(sorter_eeprom_idx, SORTER_FAIL_STATE);
  finely_position_sorter(goal_steps);
  byte sorter_index = positive_step_angle(goal_steps) / steps_per_pos;
  EEPROM.write(sorter_eeprom_idx, sorter_index);
}

unsigned int positive_step_angle(int step_angle) {
  // TODO is this stupid? should i just fail if <= -num_steps?
  while (step_angle < 0) {
    step_angle = step_angle + num_steps;
  }
  return (unsigned int) step_angle;
}

void finely_position_sorter(int goal_steps) {
  // would otherwise loop forever if goal_steps >= num_steps
  if (goal_steps >= num_steps) {
    return;
  }
  // TODO check
  int positive_goal_steps = positive_step_angle(goal_steps);
  Serial.println("goal position modulo steps per rev: " + \
    String(positive_goal_steps));
  unsleep();
  // TODO minimize delays. may need to find cause of jumping.
  delay(1000);
  while (current_steps != positive_goal_steps) {
    stepper_driver_pulse(SORTER_STEP);
    // TODO longer delay
    
    // TODO check correct
    current_steps = (current_steps + 1) % num_steps;
  }
  // TODO additional delay for it to finish step? do pulses buffer or 
  // are they completed immediately (probably later)
  delay(1000);
  resleep();
}

void vacuum_pulse(unsigned int duration_ms) {
  digitalWrite(VACUUM_VALVE, HIGH);
  delay(duration_ms);
  digitalWrite(VACUUM_VALVE, LOW);
}

void ready_experiment() {
  //move_servo(egress, EGRESS_SERVO, EXPERIMENT);
  // TODO move egress sorter (if using) to closed position
  // move input sorters to a valid position
  move_servo(entry, ENTRY_CONTROL, ENTRY_BLOCKED);
}

// TODO maybe change design such that i can suck individual flies out later?
// way to do it w/o changing design?
void end_experiment() {
  move_servo(EGRESS_SLIDER, EGRESS);
  // TODO use rotary valve or something to limit available vacuum pressure
  // to one channel at a time, if necessary to remove flies reliably
  vacuum_pulse(EGRESS_VALVE_TIME_MS);
  // better state to finish in?
  position_sorter(SEALED_SORTER_POSITION);
}

boolean fly_exiting_vial() {
  // TODO TODO TODO
  // may have to debounce / filter somehow
  //return digitalRead(FLY_ENTRY_SENSOR);
  return true;
}

// TODO could also possibly get this information from ROS tracking
// have to actuate the trap later than otherwise would (and fly might 
// fall a few times and be delayed in the meantime) with this approach.
// wouldn't check traps individually. would just check for signal that any
// were vacated.

/*
// fly passing sensor *should* correspond to a drop in reflectivity
boolean fly_exiting_trap(int i) {
  // TODO do i need to use different thresholds across traps?
  // TODO debounce / filter?
  return analogRead(trap_exit_sensors[i]) < TRAP_EXIT_THRESHOLD;
}
*/

// TODO get rid of?
void wait_for(function f) {
  while (!(*f)()) { ; }
}

// TODO how to accept variable length bool array? sizeof(boolean) = 1 byte?
// in an array do they still each take up 1 byte? bit?
boolean all_full() {
  /* TODO uncomment me!
  for (int i=0;i<NUM_TRAPS;i++) {
    if (!full[i]) {
      return false;
    }
  }
  return true;
  */
  return (full[1] && full[5]);
}

// returns the index of a randomly selected empty chamber
int get_empty() {
  // loops forever if all full
  while (true) {
    // [0,NUM_TRAPS) (traps indexed from zero, so should be correct)
    int n = random(NUM_TRAPS);
    /* TODO uncomment me
    if (!full[n]) {
      return n;
    }
    */
    // TODO delete me
    if (!full[n] && (n == 1 || n == 5)) {
      return n;
    }
  }
}

/*
// TODO could coordinate w/ ROS if i don't want to use separate sensors
void close_vacated_traps() {
  for (int i=0;i<NUM_TRAPS;i++) {
    if (full[i] && !fly_left[i]) {
      if (fly_exiting_trap(i)) {
        // TODO maybe wait / filter (also) here?
        move_servo(i, TRAP_READY);
        fly_left[i] = true;
      }
    }
  }
}
*/

// TODO
/*
void close_vacated_trap(char c) {
  // could probably do without the checks, but this will at least prevent trying to actuate
  // if we are alread there
  // TODO check no weirdness. will need to encode in ROS
  int trap_idx = (int) c;
  if (full[trap_idx] && !fly_left[trap_idx]) {
    move_servo(trap_idx, TRAP_READY);
    // TODO do i actually need this?
    fly_left[trap_idx] = true;
  }
}
*/

void let_fly_in(int i) {
  Serial.println("letting fly in channel " + String(i));
  position_sorter(i);
  ready_trap(i);
  open_entry();
  // TODO test. boolean func working? getting called? need to dereference (&)?
  //wait_for(fly_exiting_vial);
  wait_for_char();
  // move sorters to current trap

  // TODO could use reflectivity sensor to test whether fly has entered
  // has advantages and disadvantages
  // apply vacuum
  vacuum_pulse(TRAP_VALVE_TIME_MS);
  // TODO maybe put this above vacuum pulse?
  block_entry();
  
  // could also do this for all traps at the same time, and first
  // put the trap in an intermediate, sealed, position
  release_fly(i);

  // does not indicate fly has left trap to enter choice arena
  full[i] = true;
  // maybe remove this
  fly_left[i] = false;
  Serial.println("fly loaded");
}

// TODO deal w/ exit sorter too
// want to find center position of minimum pressures (sorter aligned w/ sensor)
// and set zero relative to that position w/ a defined offset
void align_sorter() {
  current_steps = 0;
  
  Serial.println("starting sorter alignment (uses pressure sensor)...");
  int measurements[num_steps];

  double sum1 = 0;
  double sum2 = 0;

  digitalWrite(VACUUM_VALVE, HIGH);
  delay(1500);
  Serial.println("measuring pressures around one full rotation...");
  unsleep();
  // TODO minimize delays
  delay(1000);
  for (int i=0;i<num_steps;i++) {
    stepper_driver_pulse(SORTER_STEP);
    measurements[i] = analogRead(SORTER_PRESSURE_SENSOR);
    Serial.print(i);
    Serial.print(": ");
    Serial.println(measurements[i]);
    sum1 += measurements[i];
  }
  delay(1000);
  resleep();
  digitalWrite(VACUUM_VALVE, LOW);

  Serial.println("calculating sensor threshold and mean motor angle...");
  // using the (at least for small n?) numerically stable 2 pass
  // variance algorithm from Wikipedia
  double mean = sum1 / num_steps;
  double diff;
  for (int i=0;i<num_steps;i++) {
    diff = ((double) measurements[i]) - mean;
    sum2 += diff*diff;
  }
  double stddev = sqrt(sum2 / num_steps);
  const double c = 3;
  int threshold = round(mean - c * stddev);
  Serial.println("stddev: " + String(stddev));
  Serial.println("threshold: " + String(threshold));

  // could have another loop setting the threshold for desired fraction of angles
  // being beneath the threshold

  // using formula from Wikipedia article on mean of circular quantities
  double sinsum = 0;
  double cossum = 0;
  double num_below = 0;
  double angle;
  const int two_pi = 6.2832;
  Serial.println("indices below threshold:");
  for (int i=0;i<num_steps;i++) {
    if (measurements[i] < threshold) {
      angle = two_pi * (((double) i) / num_steps);
      sinsum += sin(angle);
      cossum += cos(angle);
      Serial.println(i);
      num_below++;
    }
  }

  if (num_below == 0) {
    Serial.print("Error: no angles found pressure readings below threshold. ");
    Serial.println("could not find starting position. set threshold higher.");
    // TODO go into idle failure state (to not proceed into other stuff)
    
  } else {
    // probably want this around fraction of circumference holes occupy
    // maybe a little wider, since tube isn't a infinitesimal point (~0.05). change c to get it.
    Serial.println("fraction of indices below threshold: " + String(num_below / num_steps));
    int mean_lowpressure_step = round(atan2(sinsum, cossum) / two_pi  * num_steps);
    Serial.println("new zero in current coordinates: " + \
      String(mean_lowpressure_step + SORTER_ALIGNMENT_OFFSET));
    // TODO test that on a few revolutions, the minimum is in the same place?
    // sum of differences of measurement array < some threshold?
  
    Serial.println("moving to new zero position...");
    // current zero is where we happened to start taking measurements
    // we want to move to the center of low pressure area + offset
    // and then define that as the new zero globally
    // TODO test sorter positioning functions with negative arguments
    finely_position_sorter(mean_lowpressure_step + SORTER_ALIGNMENT_OFFSET);
    current_steps = 0;
  }
}

// only runs at the end of each loop(), so check it can tolerate delays
// there are more real-time ways of doing this
void serialEvent() {
  // TODO robust enough? i don't want a longer message to get fragmented though...
  char c = (char) Serial.read();
  // this character will be the signal to end the experiment
  if (c == 'E') {
    end_experiment();
  } else {
    // TODO
    //close_vacated_trap(c);
  }
  // TODO check for errors?
}

// TODO make sure all pins / used variables #defined / declared are referenced here
void setup() {
  Serial.begin(9600);
  pinMode(LED_BUILTIN, OUTPUT);
  digitalWrite(LED_BUILTIN, LOW);
  
  // make sure all pins that are supposed to be outputs are set here
  pinMode(VACUUM_VALVE, OUTPUT);
  pinMode(SORTER_STEP, OUTPUT);
  pinMode(SORTER_SLEEP, OUTPUT);
  pinMode(ENTRY_CONTROL, OUTPUT);
  pinMode(EGRESS_SLIDER, OUTPUT);

  // you don't strictly need all of these calls
  // but it helps ensure near total independence from previous state of the Arduino
  digitalWrite(VACUUM_VALVE, LOW);
  digitalWrite(SORTER_STEP, LOW);
  digitalWrite(SORTER_SLEEP, LOW);
  digitalWrite(EXIT_SORTER_STEP, LOW);
  digitalWrite(EXIT_SORTER_SLEEP, LOW);
  digitalWrite(ENTRY_CONTROL, LOW);
  digitalWrite(EGRESS_SLIDER, LOW);

  for (int i=0;i<NUM_TRAPS;i++) {
    int servo = FIRST_TRAP + i * 2;
    
    pinMode(servo, OUTPUT);
    digitalWrite(servo, LOW);
    trap_servo_pins[i] = servo;

    full[i] = false;
    fly_left[i] = false;
  }

  // INPUT is the default pin mode, but just to be clear
  pinMode(FLY_ENTRY_SENSOR, INPUT);
  pinMode(SORTER_PRESSURE_SENSOR, INPUT);
  
  sorter_sleeping = true;
  byte sorter_position = EEPROM.read(sorter_eeprom_idx);
  if (ALIGN_SORTER || sorter_position == SORTER_FAIL_STATE) {
    align_sorter();
  } else {
    current_steps = sorter_position * steps_per_pos;
  }

  correct_servo_positions();
  /* set this true if the servo plate is already attached! */
  if (!SERVO_PLATE_ATTACHED) {
    attach_servo_walkthrough();
  }
  //TODO maybe not always?
  //test_servos();

  ready_experiment();
}

/* TODO:
-how to coordinate experiment state w/ ROS nodes (when to suck flies in/out,
 ,etc)?
-is this also controlling shock? may need more pins then? (maybe just 1, or shift)
-drive sorter gears only in one direction
-pick chamber to send fly to randomly from available (not sequential) 
-NEED TO REWRITE let_fly_in TO ACCOMODATE CONSTANT CHECKS FOR FLIES WALKING INTO
 CHAMBERS FROM TRAPS (by checking reflectivity sensors)
*/

void loop() {
  // TODO will also probably need to check for vacated traps (separately?)
  while (!all_full()) {
    int chamber_num = get_empty();
    let_fly_in(chamber_num);
    // TODO remove
    full[1] = false;
    full[5] = false;
  }
  
  // TODO the arduino could technically be put into a lower power state when
  // all_full. may not be of any value.

  // TODO support sNN{L/R}, cNN, end (anything else?)
  // a reason to send which chambers are full to ROS: could not track some chambers unless a fly is expected
  

  // this is where serialEvent checks to for input
  // (ROS nodes may send the Arduino a character telling it to end the experiment)
  // TODO refactor everything to check this more frequently (less blocking) (the check for vacated traps at least)
  
}

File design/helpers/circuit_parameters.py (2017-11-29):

#!/usr/bin/env python

from __future__ import division
import numpy as np

###############################################################################
# Assumptions
###############################################################################
# TODO measure
# maybe w/ oscilloscope? i wasn't really getting readings fast enough w/ a DMM 
# on 20M resistance range
'''
min_fly_resistance = 1e6
# could try 1e7-1e9. previously suspected typical was ~29Mohm, which is 2.9e7
max_fly_resistance = 1e9 # 1Gohm
'''
min_fly_resistance = 5e7 / 5
max_fly_resistance = 5e7 * 5


###############################################################################
# Requirements
###############################################################################
max_operation_voltage = 120 # 100?
typ_operation_voltage = 60
# ?
min_operation_voltage = 20

# error relative to nominal value. x100 to get a percentage.
#max_fractional_voltage_change = 0.01
max_fractional_voltage_change = 0.02


###############################################################################
# Overvoltage protection
###############################################################################

# TODO still reasonable at lower operating voltages? probably?
max_safe_voltage = 200
zener_drop = 5.1 # V
# 1 W = 1 V * 1 A
zener_power_dissipation = 0.5 # W (500mW)
# it may get harder to find (small / cheap) resistors to dissipate
# more power than this
max_resistor_power = 1 # W
limit_resistor_voltage = max_safe_voltage - zener_drop

# TODO is this correct?
max_fault_current = min(zener_power_dissipation / zener_drop, \
    max_resistor_power / limit_resistor_voltage)

# V = I*R, I=V/R
min_limit_resistor = max_safe_voltage / max_fault_current

# P = I*V
limit_resistor_power = limit_resistor_voltage * max_fault_current

print 'for protection against at most {:,}V'.format(max_safe_voltage)
print 'using a Zener with Vz={} and capable of dissipating {}W of power'.format(\
    zener_drop, zener_power_dissipation)
print 'maximum overvoltage current of {}A'.format(max_fault_current)
print 'minimum limit resistance of {:,} ohms'.format(min_limit_resistor)
print 'this resistor will dissipate {}W of power\n'.format(limit_resistor_power)


###############################################################################
# Digital optoisolators
###############################################################################

# TODO revisit. see notes in sheet w/ this part.
'''
logic_level = 5 # volts

# parameters for TLP2531
max_led_current = 0.025 # 25mA
led_current_goal_over_max = 0.8

led_limit_resistor = logic_level / (0.8 * max_led_current)

# current-transfer-ratio (on [0,1])
ctr_typ = 0.3
# see https://www.vishay.com/docs/83741/83741.pdf
extra_ctr_tolerance = 0.8 * 0.75
# different from min CTR in datasheet (probably more optimistic, too)
min_expected_ctr = ctr_typ * extra_ctr_tolerance

# from SN74HC595 datasheet
# actually specified at Vcc=4.5v, so real values are probably a little higher
# for Vcc=5v (I adjusted a little)
min_logic_high_voltage = 3.5
max_logic_low_voltage = 1.5

print 'resistor to limit optoisolator LED current: {:,} ohms\n'.format(\
    led_limit_resistor)
'''

#charge_time_at_min_current = 
# digikey lists some (slightly) different parameters for what they call
# Digi-Key PN: CD4051B-DIE-ND, Mfg PN: CD4051B
# and
# Digi-Key PN: 296-2057-5-ND, Mfg PN: CD4051BE
# TODO is this an error? what does the E mean?
# the page for the latter seems to link to a TI datasheet of a part
# w/o an E in the suffix, and the former doesn't have a datasheet link
# might not matter, b/c the former has 0 currently available... ?

# TODO worth building in alternate route for a current reference to be passed
# over the sense resistor, for calibration?
# http://www.resistorguide.com/applications/shunt-resistor/
# I'm thinking no, for now...

# TODO should i add capacitors on the floor pcb to null inductance in the connector wires?
# or would that not make sense because the driver is also off of the floor pcb?

# TODO should i switch to using high side FETs
# (i think i would need to get a consistent voltage relative to variable Vhigh_voltage)
# so that i can measure with small resistors with single ended measurements?

adc_bits = 10
adc_levels = 2**adc_bits
vmin_adc = 0
vmax_adc = 5
# a.k.a. least significant bit (LSB)
v_per_level = (vmax_adc - vmin_adc) / adc_levels
# TODO also take in to account errors reported in datasheet (should be in terms of LSB)
# TODO and are those reported values w/ internal references? could be improved
# w/ external reference?

# TODO decide whether to shut off at this current, or maybe some multiple of it?

# IRL620 properties
# at Vgs=5V

# may depend somewhat on Ids, and thus not really be tested at
# low currents it will see here?
fet_rds_on = 1
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

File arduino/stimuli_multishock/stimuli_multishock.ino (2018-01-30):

// Author: Tom O'Connell <toconnel@caltech.edu>

#include <stimuli.hpp>
#include <multishock.hpp>
// TODO how to publish w/o nodehandle? should be able to...
#include <ros.h>
// TODO include this generated type in multishock library?
#include <choice/ChannelMeasurementMicros.h>

// will use fet_enbl pin (output enable on shift register controlling FETs)
// to switch shock on and off, just as I used to use pins for this


static choice::ChannelMeasurementMicros cm_stamped;
// static cause problems?
// TODO why does it need to be initialized w/ address, and then also passed
// address on call to publish?
static ros::Publisher measurement_pub("channel_measurements", &cm_stamped);

// TODO make ROS msg type for this in choice package, and include generation as
// w/ stimuli package?
void send_measurement() {
  // should be 16 bits.
  msk::channel_measurement_t cm;
  // TODO might be faster / preferable to just measure each channel explicitly
  // in a for loop
  cm_stamped.channel_measurement = msk::measure();
  // should wrap around every 70 minutes or so. will need to take in to account.
  // TODO maybe it is unrealistic to ever be able to get two "packets" sent in a
  // millisecond though? 
  cm_stamped.micros = micros();
  
  measurement_pub.publish(&cm_stamped);
}

void setup() {
  // TODO make sure these don't conflict
  msk::init();
  // TODO provide function to publish / get nodehandle if necessary
  // maybe get rid of ROS import?
  // TODO need two init functions? is nodehandle existant at this point?
  stim::get_nodehandle()->advertise(measurement_pub);
  stim::init();

  stim::while_idle(send_measurement);

  msk::start_measuring_all();

  // should disable FET register output
  // will control shock to flies with this pin
  digitalWrite(msk::fet_enbl, LOW);
  // will control shock w/ enable pin
  msk::start_shock_all();
}

void loop() {
  // would be simpler... but i feel like i need more control to get the
  // measurements back out too, unless i make could also register functions w/
  // (arbitrary?) return types easily
  stim::update();
}

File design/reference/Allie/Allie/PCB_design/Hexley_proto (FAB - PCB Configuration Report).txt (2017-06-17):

PCB Configuration Report
------------------------

Report File:        C:\Users\user\Documents\Allie\PCB_design\Hexley_proto (FAB - PCB Configuration Report).txt
Report Written:     Tuesday, June 28, 2016
Design Path:        C:\Users\user\Documents\Allie\PCB_design\Hexley_proto.fab
Design Title:       
Created:            6/27/2016 3:04:22 PM
Last Saved:         6/28/2016 11:42:58 AM
Editing Time:       296 min
Units:              mm (precision 4)

PCB Artist version:       3.1


Design Requirement
------------------
Design Requirement Name:  2 Layer Standard


Board
-----
Board Size:               250.0000 X 201.8000
CNC Route Points:         4


Layers
------
Number of Layers:         2
Powerplanes:              No
Solder Mask:              Yes
    Top Side:             Yes
    Bottom Side:          Yes
    Type:                 LPI
    Color:                Green
Silkscreen:               Yes
    Top Side:             Yes
    Bottom Side:          No
    Color:                White


Board Parameters
----------------
Material:                 FR4
Material Thickness:       1.5748 mm
Finish Plating:           Lead Free Solder
Copper Weight:            1 oz

Tab Routes:               No
V-Scoring:                No
Plated Slots:             No
Plated Edges:             No
Dielectric:               No
Impedance:                No
Counter Sinks:            No
Counter Bores:            No

Min Track Width (Outer):  0.2540 mm
Min Track Width (Inner):  0.2540 mm
Min Spacing (Outer):      0.2540 mm
Min Spacing (Inner):      0.2540 mm
Minimum Hole Size:        0.3810 mm
Beveled Gold Fingers:     None


Additional Requirements
-----------------------
Electrical Test:          No
Component Assembly:       No
        Unique Component Parts: 0
        Through Hole:     0
        Fine Pitch:       0
        BGA/Leadless:     0
        Other SMT:        0

Special Requirements: 



Production
----------
Board Part Number:        1
Revision Number:          1
Production:               Prototype
Turnaround Time:          3 Days
Quantity:                 1
Array:                    No

Board Unit Price:         $340.05
Board Subtotal Price:     $340.05
Test Price:               $0.00

Total Price:              $340.05


Design Data
-----------
Number of Tracks:         367
Minimum Outer Track Width Used:1.0000 mm
Maximum Outer Track Width Used: 1.0000 mm

Number of Holes:          8
Number of Hole Sizes:     1
Minimum Hole Size Used:   0.8890 mm
Maximum Hole Size Used:   0.8890 mm

Number of Top SMT Pads:   0
Number of Bottom SMT Pads: 0

Minimum Track (Outer):    0.2540 mm

Fiducials:                No

Number of Design Errors:  216

End Of Report.

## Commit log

2017-06-14 Initial commit. Will probably redesign bottom plate and vacuum trap sliders, to facilitate mounting and move motors out of lighting path.
    [bottom_two_thirds_of_vacuum_trap.fcstd, funnel_servo_arm.stl, rough_tubing_support.fcstd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]
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2017-06-15 .ino includes stepper commands. Not fully proofread. Added design files for sorter Dan sent me.
    [Flysorter.SLDASM, InnerBase.SLDPRT, InnerCap.SLDPRT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]
2017-06-16 Inkscape (b/c version change?) required rescaling svgs. Should still be correct. Resaved my svgs as dxfs for editing in librecad.
    [bottom_plate.dxf, delrin_chambers_and_manifold.dxf, pcb_side_spacers.dxf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]
2017-06-17 Added all material Allie compiled (downloaded from Hong lab NAS) to design/reference. Added attribution.
    [#1.dwg, #1.dxf, 1.SLDPRT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]
2017-06-18 Working on lining up vacuum traps (and appropriately modifying other layers), restarting from Allie's DXFs but keeping some features of my last design.
    [#1.dxf, 1.dxf, 2.dxf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]
2017-06-22 Initial draft of shaft doubler, but need to add top mount holes. First draft of v2 choice chambers was cut, but thin Delrin against chambers curled.
    [olfactory_shock_conditioning_chambers_NO_SVG_INTERMEDIATE.dxf]
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2017-06-22 Removed extraneous blocks, corrected instances when things weren't the block version when they should have been, and made 10-32 through holes bigger.
    [olfactory_shock_conditioning_chambers_NO_SVG_INTERMEDIATE.dxf]
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2017-06-28 Widened guides between last two commits, but was probably a mistake, since sliders printed recently are mysteriously narrower. May need to fix. Started breaking out old design components into modular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
    [modular_vacuum_trap.dxf, olfactory_shock_conditioning_chambers.dxf, olfactory_shock_conditioning_chambers_NO_SVG_INTERMEDIATE.dxf]
2017-06-28 Made vacuum trap flow feature a polyline to try to fill in Coreldraw. Might hurt things later.
    [olfactory_shock_conditioning_chambers.dxf]
2017-06-28 Made guides narrower again, b/c it turns out traps in this design are a little thinner.
    [olfactory_shock_conditioning_chambers.dxf]
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2017-06-29 First draft without glue necessary to seal sliders (ideally). Hoses coming out of bottom. Slot in bottom plate to accomodate.
    [olfactory_shock_conditioning_chambers.dxf]
2017-06-29 Widened all inner through holes in delrin & shim layers, to prevent screws coming up through support from making the layers non-flush. Also widened space around 10-32 inlet in those layers since thre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
    [olfactory_shock_conditioning_chambers.dxf]
2017-06-30 Slider updated to allow a more realistic amount of space. May need to shrink it back on bottom edge ~.5mm or so. May want to make symmetric in case any visible light.
    [olfactory_shock_conditioning_chambers.dxf]
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2017-07-02 Refactored servo code a little b/c can't declare more than 48 servos (on Mega, even less on other boards) w/o having excess not work (it seems).
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2017-08-09 Initial thoughts on some python nodes I'd need. Likely won't use.
    [loader.ino]
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2017-08-19 Fixed pin printing and PulseSeq states definition in shock_transitions.
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2017-09-15 Data centered, patches showing correctly with legend. Still need to check sides aren't flipped in some places and filter bad data.
2017-09-18 Added clamps to delrin_chambers_and_manifold. Not sure what changes were made to other file... CHECK
    [delrin_chambers_and_manifold.dxf, olfactory_shock_conditioning_chambers.dxf]
2017-09-18 Added 1/4-20 clearance holes at right spacing for current aluminum frame. Changed all holes that had magnets ONLY SO FAR IN SUPPORT LAYER to 8-32 tap. Need to change upper layers to be clearance for 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
    [olfactory_shock_conditioning_chambers.dxf]
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2017-09-21 Fixed x-axis label not showing up on the bottom subplot. Printing how many rejected for each reason / good / total
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2017-09-25 Patching in stimulus regions for traces during labelling mostly correctly now. Could only improve ylim a little.
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2017-10-04 Made most holes in acrylic baseplate just under 7/32 for brass inserts.
    [olfactory_shock_conditioning_chambers.dxf]
2017-10-10 Updated delrin + shim through holes to 8-32 free fit, made holes for brass inserts in bottom plate a little wider for less cracking, added PCB floor outline, added spacers (though maybe should be blo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
    [olfactory_shock_conditioning_chambers.dxf]
2017-10-10 Made delrin layer dividers into a block, and started refactoring to not have any channels cross a gap (junction between PCB and spacers was current problem). May want to make PCB wider? or redo clamp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
    [olfactory_shock_conditioning_chambers.dxf]
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2017-10-18 Tried starting unit for pockets / holes in PCB layer, but ran into what seemed like a bug in Librecad (line segment extended to beyond screen in either direction). Going to try in different versions 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
    [olfactory_shock_conditioning_chambers.dxf]
2017-10-18 Starting little python script to generate vertices for one PCB grid unit. Updated PCB pocket blocks?
    [olfactory_shock_conditioning_chambers.dxf]
2017-10-18 Trying to not have all the traces get squished, and testing fixed aspect ratio, but haven't looked at output yet.
2017-10-18 Finished initial code to generate electrode grid vertices, and used that to make a small hierarchy of blocks for the grids.
    [olfactory_shock_conditioning_chambers.dxf]
2017-10-19 Moved traces in PCB that would go through holes in the PCB around holes, but I probably don't want a lot of those traces anyway because I want the grids independent, so will probably undo a lot of th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
    [olfactory_shock_conditioning_chambers.dxf]
2017-10-25 If any real changes, more changing grid blocks to route traces around pockets in the PCB. Will revert DXF to probably b610d1ea for import into KiCAD
    [olfactory_shock_conditioning_chambers.dxf]
2017-10-25 Using b610d1ea olfactory_shock_conditioning_chambers.dxf. Haven't yet updated grids. Code now generates full grid + w/ one central tooth
    [olfactory_shock_conditioning_chambers.dxf]
2017-10-26 Generating some kind of pad output, but doesn't seem to be interpreted as I want it. May try to switch to zone?
2017-10-27 Think I figured out how to draw polygons as pads. Going to clean up some commented code that didn't work, try to get rid of some unneeded pcbnew api calls, and clean up other footprint properties / c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
2017-10-27 Initial (mostly empty) kicad files. make_board doesn't really do anything now, just boilerplate. Trying to get dxf to import from pcb layer in master LibreCAD dxf into KiCAD edge cut layer.
    [olfactory_shock_conditioning_chambers.dxf, pcb.kicad_pcb, pcb.sch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]
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2017-11-01 Made two custom (S/D)IP footprints with slightly larger clearances. Mostly fixed custom electrode footprint pad anchor points.
    [pcb.dsn, pcb.kicad_pcb, pcb.sch]
2017-11-02 Fixed width of electrodes being made thicker, since 0 thickness for primitive was being changed to a nonzero default.
2017-11-06 Changed layer set in electrode_vertices + layer references are on. Placing pair of connectors symmetrically in make_board and setting title block there.
    [pcb.kicad_pcb]
2017-11-06 Re-ordered some pins in sch and regenerated netlist. Increased y margin to connectors for extra space for routing. Finished routing of board with original footprint geometry.
    [pcb.kicad_pcb, pcb.sch]
2017-11-06 Cleaned up intermediate file and renamed to floor_pcb*, since I'm also going to add shield files (maybe in same dir?)
    [floor_pcb.kicad_pcb, floor_pcb.sch, pcb.dsn]
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2017-11-07 Added some reference material, a paper and some recommendations sent from Daniel Wagenaar. Renamed pcb with grids to floor_pcb, created project for Arduino shield.
    [floor_pcb.kicad_pcb, floor_pcb.sch, shield_pcb.kicad_pcb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]
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2017-11-10 Added schematic lib w/ IRL620 symbol for shield. Going to convert FET / measurement unit to hierarchical sheet. Not sure what changes were to floor_pcb.sch.
    [floor_pcb.sch, shield_pcb.sch]
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2017-11-10 Refactored (draft) of one unit into switch_and_signal. May remake parent from Arduino shield template.
    [shield_pcb.sch, switch_and_signal.sch]
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2017-11-13 May include some of the refactoring of the schematic into Arduino shield template. Updated library references b/c 2337b83b kicad build wanted it. Broke some things and will need to fix.
    [shield_pcb.kicad_pcb, shield_pcb.sch, signals_to_adc.sch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]
2017-11-13 Fixed shield schematic, at least for KiCad <= d8f4e35. Added notes to single measurement unit. Updated IRL620 library part to include correct datasheet, etc.
    [shield_pcb.sch, signals_to_adc.sch, switch_and_signal.sch]
2017-11-14 working on analog demultiplexer / amplifier circuit. going ahead with CD4052B for now. still need to select opamp / peripherals + shunt value. using cd4556b to select analog switch. added its datashe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
    [shield_pcb.sch, signals_to_adc.sch, switch_and_signal.sch]
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2017-11-14 Picked AD623 instrumentation amplifer to be downstream of analog switches. I think I'm mostly done with demux to ADC subcircuit, apart from setting the gain and maybe some more decoupling caps. Added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
    [signals_to_adc.sch]
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2017-11-22 Working on shift registers and optical isolators. Don't think I'll try to find some elegant solution to use chips to cycle through shocked channels. May keep measurement SR separate. Added most datas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
    [shield_pcb.sch, signals_to_adc.sch, switch_and_signal.sch]
2017-11-22 Mostly done with digital input isolation subsheets. Planning to refactor switch_and_signal.sch to this directly, as other subsheets. May break.
    [digital_input_isolation.sch, optoisolator_with_peripherals.sch, shield_pcb.sch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]
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2017-11-25 Corrected bug in code to test channel selection (one bit inverted), and added some test signals for analog switch.
    [shift_register_optocoupler_test.ino]
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2017-11-28 Added report from wizard failing to properly convert the (schematic?) library handling in this project to the new method. May be useful in ultimately being able to modernize.
2017-11-28 Have some basic SPICE working, with the goal of checking the overvoltage protection, but also to verify voltage drops. Measured fly resistance a little better than I had done before, and it comes out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
    [digital_input_isolation.sch, optoisolator_with_peripherals.sch, shield_pcb.sch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]
2017-11-29 Finished a large portion of routing. May undo some of it to switch to >1-1.4mm clearance on at least the very input nets. Actually, maybe I won't... none of the other components are really designed t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
    [digital_input_isolation.sch, optoisolator_with_peripherals.sch, shield_pcb.kicad_pcb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]
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2017-12-05 Deleted most tracks. Replaced SMD Zener w/ through hole. Going to try to redo placement and then routing. Last placement may have been unroutable.
    [shield_pcb.kicad_pcb, switch_and_signal.sch]
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2017-12-05 Back imported autorouter output. Fixed DRC errors in Arduino inputs seemingly caused by numerical errors. Going to try to setup ground / power planes.
    [shield_pcb.dsn, shield_pcb.kicad_pcb]
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2017-12-06 Updated electrode_vertices.py to also generate electrodes interleaved along the long axis, for an orthogonal set of ceiling electrodes. New *_lengthwise footprint should be correct, if not a little w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
    [ceiling_pcb.kicad_pcb, ceiling_pcb.sch, ceiling_pcb_edges.dxf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]
2017-12-06 Fixed bug I made in electrode vertices. Ceiling pcb pretty much done. Need to name F<N> nets consistently across Kicad projects.
    [ceiling_pcb.kicad_pcb, ceiling_pcb.sch, floor_pcb.kicad_pcb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]
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2017-12-07 Added scripts to zip Gerber files and rename them. Shield seemed to need fed through gerbv for Advanced Circuits FreeDFM to be happy with it, but that doesn't seem true with the floor... Unexpected. 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
    [ceiling_pcb.kicad_pcb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]
2017-12-12 Added script to generate OpenSCAD script, which can then generate a 3D model of the behavior chambers. TODO use similar approach to get PCB outlines for Kicad, integrate w/ Kicad 3D, workaround DXF l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
    [olfactory_shock_conditioning_chambers.dxf, olfactory_shock_conditioning_chambers.scad]
2017-12-12 Changed vacuum trap active layer to red so it is rendered, but splines still broken. Rendered invidual layers in SCAD for troubleshooting, and took notes on where things are going wrong.
    [0.2a_slider_compression.scad, 0_servo_arm.scad, 1.1_top_acrylic_manifold_sides.scad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]
2017-12-12 Made second round of floor pcb gerbers, still before ordering because first quotes were really expensive. Needed to add soldermask, but still having some slight issues (can't make clearance more than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
    [floor_pcb.kicad_pcb, optoisolator_with_peripherals.sch, shield_pcb.kicad_pcb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]
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2017-12-13 Before another attempt fixing symbol libraries in floor_pcb
    [floor_pcb.sch, shield_pcb.sch]
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2017-12-13 Before pushing attempt at fixing ceiling through EEschema load / save.
    [ceiling_pcb.sch]
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2017-12-14 Added install script for hole fixing kicad plugin.
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2018-01-08 Fixed pin mapping on LT1118-5 linear regulator (ground and 5v out swapped on first ordered PCBs)
    [shield_pcb.kicad_pcb, shield_pcb.sch]
2018-01-08 Fixed pinswap on power supply (Vout + and -)
    [shield_pcb.kicad_pcb, shield_pcb.sch]
2018-01-09 Fixed pinswap of drain and source on each MOSFET. Tore up routing but TODO re-route.
    [digital_input_isolation.sch, shield_pcb.kicad_pcb, shield_pcb.sch]
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2018-01-11 Starting to refactor test code into Arduino library. Not working yet, and most test files + library files are stubs / empty.
    [digital_input_isolation.sch, optoisolator_with_peripherals.sch, signals_to_adc.sch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]
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2018-01-15 Fixed StartStopMeasureLast library test and added Arduino library testing README.
2018-01-15 Fixed typo in a for loop, now compiling in Arduino environment.
2018-01-15 Cut code from (just deleted) test ino, and pasted into separte tests in example subdirectory of library. Need to fix.
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2018-01-23 Fixed bugs in test_demux_fet_indexing_match and after some hardware tweaking, one board is working! On to the amplifier circuitry / testing with flies.
2018-01-23 Notes on single channel current draw / temperature during overvoltage short.
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2018-02-07 Added initial code to plot currents from extra extra nodes that get this information off of the Arduino. Hard coded new pins into analysis + bugfix.
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2018-02-13 Blockified the majority of the shared parts. Fixed ceiling. Made most edges go out further (for prototyping magnets later).
    [delrin_chambers_and_manifold.dxf, olfactory_shock_conditioning_chambers.dxf, yellow_manifold_layer.dxf]
2018-02-14 Fixed lid for clear PCB that was too short to reach bottom contacts. Also made space in inner layers for top contact.
    [olfactory_shock_conditioning_chambers.dxf]
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2018-02-15 Imported new ceiling edges to kicad. Too short, but will go ahead and make this way. Not sure full length for pads would fit w/ DSUB
    [ceiling_pcb.kicad_pcb, ceiling_pcb_edges.dxf]
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2018-02-22 Tried to load hardcoded stimulus information in a way that would work with old data. At least some old data seems to be missing this information. Some extra debugging prints in now.
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2018-04-19 Added missing step in README to install Arduino libraries. Added description on how to stop running ROS to clear params.
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2018-05-22 Updated floor_pcb to Edge.Cuts repr of through holes, fixed trace that intersected one hole, and updated diam of outer holes to same 6-32 clearance. KiCAD df2819e crashing on zone fill attempt.
    [floor_pcb.kicad_pcb, floor_pcb_edges.dxf, olfactory_shock_conditioning_chambers.dxf]
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2018-05-30 Trying to explode layers I want to cut now, for use in Inkscape. Some stuff was flipped in master.
    [one_ver_of_toxic_layers_exploded.dxf]
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2018-06-21 Fixed legend for traces subplots (non-interactive, at least). + fixed pre_post report bug.
2018-06-21 Finished (hopefully still non-broken) MFC mounting plate. Working on similar mounts for rest of olfactometer.
    [olfactometer_mounting_plates.fcstd]
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2018-06-22 Re-exported correct humidifier bottom mount plate.
    [humidifier_bottle_mount_bottom.dxf]
2018-06-25 Fixed error in MFC mounting hole layout.
    [mfc_mounting_plate.dxf, olfactometer_mounting_plates.fcstd]
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2018-07-06 Fixed immediate bugs in case where there are no good flies.
2018-07-06 New masks. Often easiest to get horz to double print well, b/c minimal length change over short width of first piece.
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2018-07-12 Fixed olfactometer inlet to box sides to be sufficiently high above chamber.
    [box_side.dxf, chamber_parts.fcstd]
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2018-09-11 Fixed case odor breakdown in case where one odor has no good flies.
2018-10-15 Fixed missing unit in delrin layer with doors.
    [olfactory_shock_conditioning_chambers.dxf]
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2018-12-01 More backlash aware calibration and moving. Fns to test doors. Support for new vent doors.
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2018-12-14 Refactored calibration code a little and now visiting all vent doors more accurately, without as much manual correction.
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
